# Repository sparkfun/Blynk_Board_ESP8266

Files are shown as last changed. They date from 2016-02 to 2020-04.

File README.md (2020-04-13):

SparkFun Blynk Board - ESP8266
========================================

SparkFun Blynk Board - ESP8266 (https://www.sparkfun.com/products/13794)

[*SparkFun Blynk Board - ESP8266 (WRL-13794)*](https://www.sparkfun.com/products/13794)

The SparkFun Blynk Board is specially designed to work with the [Blynk mobile app](http://blynk.cc), for iOS or Android devices. Combining the Blynk Board with the Blynk app, you'll be able to easily complete a variety of Internet-of-Things (IoT) based projects: control LEDs from your phone! Wire up a door switch and receive phone notifications when it opens or closes. Plug a soil moisture sensor into a plant, and have it tweet at you when it's thirsty!

BotaniTweet Project (https://learn.sparkfun.com/tutorials/blynk-board-project-guide/)

All of these projects - and more! - are pre-loaded into the Blynk Board. All you have to do is provision it (using the Blynk app), and start tinkering!

Repository Contents
-------------------

* **/Firmware** - Blynk Board core firmware and example code.
* **/Hardware** - Eagle design files (.brd, .sch)
* **/Production** - Production panel files (.brd)

Documentation
--------------
* **[Getting Started Guide](https://learn.sparkfun.com/tutorials/getting-started-with-the-sparkfun-blynk-board)** - Learn how to connect your Blynk Board to Wi-Fi, and start Blynking!
* **[Blynk Board Project Guide](https://learn.sparkfun.com/tutorials/blynk-board-project-guide/introduction)** - Explore over a dozen Blynk projects pre-loaded into the Blynk Board.
* **[Blynk Board Arduino Development Guide](https://learn.sparkfun.com/tutorials/blynk-board-arduino-development-guide)** - Learn how to begin programming the Blynk Board using Arduino, so you can create projects of your own!
* **[SparkFun Graphical Datasheets](https://github.com/sparkfun/Graphical_Datasheets/tree/master/Datasheets/ESP8266/BlynkBoard)** -Graphical Datasheets for the SparkFun Blynk Board.

Product Versions
----------------
* [SparkFun Blynk Board - ESP8266 (v1.0) (WRL-13794)](https://www.sparkfun.com/products/13794)- Initial release of the SparkFun Blynk Board - ESP8266.
* IoT Starter Kit with Blynk Board
  * [(KIT-14682)](https://www.sparkfun.com/products/14682) - Updated parts kit with thicker resistor leads.
  * [(KIT-13865)](https://www.sparkfun.com/products/13865) - A parts kit including the SparkFun Blynk Board.

Version History
---------------
* [HW v1.0, FW v1.0.3](https://github.com/sparkfun/Blynk_Board_ESP8266/releases/tag/HW_v1.0-FW_v1.0.3) - Minor update for ESP8266 Community board add on (v2.6.0 and above) when using interrupts.
* [HW v1.0, FW v1.0.2](https://github.com/sparkfun/Blynk_Board_ESP8266/releases/tag/HW_v1.0-FW_v1.0.2) - Initial release of the SparkFun Blynk Board hardware and firmware.

License Information
-------------------

This product is _**open source**_! 

Please review the LICENSE.md file for license information. 

If you have any questions or concerns on licensing, please contact technical support on our [SparkFun forums](https://forum.sparkfun.com/viewforum.php?f=152).

Distributed as-is; no warranty is given.

- Your friends at SparkFun.

_<COLLABORATION CREDIT>_

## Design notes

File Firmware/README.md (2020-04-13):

# SparkFun Blynk Board - ESP8266 Core Firmware

The [SparkFun Blynk Board - ESP8266](https://www.sparkfun.com/products/13794) firmware allows you to configure a Blynk Board's WiFi network and Blynk auth token. Then, once the board is equipped with network access and a connection to the Blynk Cloud, the firmware is equipped with ten Blynk experiments, which allows you to test out the Blynk Board and the Blynk app without ever bothering to re-program the board's ESP8266 WiFi/microcontroller.

### Firmware Contents

To better navigate the firmware's functionality, the source code is divided into a number of separate files:

* **[BlynkBoard_Core_Firmware.ino](https://github.com/sparkfun/Blynk_Board_ESP8266/Firmware/BlynkBoard_Core_Firmware.ino)** -- Main source file, where `setup()` and `loop()` are defined. Also controls the RGB LED status indicator.
* **[BlynkBoard_Setup.ino](https://github.com/sparkfun/Blynk_Board_ESP8266/Firmware/BlynkBoard_Setup.ino)** -- Hardware setup and EEPROM/flash reading/writing.
* **[BlynkBoard_ConfigMode.ino](https://github.com/sparkfun/Blynk_Board_ESP8266/Firmware/BlynkBoard_ConfigMode.ino)** -- Configuration mode functions; AP and serial WiFi/Blynk configuration.
* **[BlynkBoard_BlynkMode.ino](https://github.com/sparkfun/Blynk_Board_ESP8266/Firmware/BlynkBoard_BlynkMode.ino)** -- Blynk mode functions, including definition of all Blynk Board introductory experiments.
* **[BlynkBoard_settings.h](https://github.com/sparkfun/Blynk_Board_ESP8266/Firmware/BlynkBoard_settings.h)** -- Various constant settings, including RGB colors and connection timeouts.

### Using Arduino to Upload to the Blynk Board

For help adding Blynk Board support to your Arduino IDE, check out our [Blynk Board Arduino Development Guide](https://learn.sparkfun.com/tutorials/blynk-board-arduino-development-guide).

You can install the board definitions using the **Arduino Board Manager**. Just paste the link below into the "Additional Board URL's" textbox, in Arduino properties:

	http://arduino.esp8266.com/stable/package_esp8266com_index.json

After installing the Arduino ESP8266 board definitions, you'll find a option for "SparkFun Blynk Board" under the **Tools** > **Board** menu - select that, and upload some code!

### Custom Libraries Used

If you are installing the Bynk Board Core Firmware, you will need to install a few Arduino libraries. For more infomration, check out the tutorial for intsalling an Arduino Library.

* **[Installing an Arduino Library Guide](https://learn.sparkfun.com/tutorials/installing-an-arduino-library)** - Basic information on how to install an Arduino library.

The following libraries were used with the default Blynk Board Core Firmware:

* [Blynk Arduino Library](https://github.com/blynkkk/blynk-library/releases/tag/v0.3.4)
* [SparkFun HTU21D](https://github.com/sparkfun/SparkFun_HTU21D_Breakout_Arduino_Library/releases/tag/V_1.1.1)
* [Adafruit NeoPixel](https://github.com/adafruit/Adafruit_NeoPixel)
* [SparkFun TSL2561 Library](https://github.com/sparkfun/SparkFun_TSL2561_Arduino_Library/releases/tag/V_1.1.0)

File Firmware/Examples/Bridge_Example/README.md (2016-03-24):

These two example sketches are nearly identical. The key difference is the
authentication tokens will be swapped in the two. This example code for the
SparkFun Blynk Board demonstrates the functionality of the Bridge widget.
Using two of these boards to send signals from one board to the other, or from
one connected mobile device to either Blynk Board or another mobile device if
available. Simple wireless buttons and a more complex chat app are part of this
demo.

For more information please see the [tutorial](https://learn.sparkfun.com/tutorials/blynk-board-bridge-widget-demo/) on the SparkFun website.

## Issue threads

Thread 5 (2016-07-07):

Firmware + Interrupts

mrmolex, 2016-07-07:
Hi!.  The digital pins can handle interrupts? in which pins? what limitations have?.  NOTE: i need to count a pulse signal with a max. frequency of 2 Hz.

bboyho, 2020-04-13:
Hi,

This case looks stale and does not seem to be an issue with the Blynk board or core firmware. However, I can answer a few of your questions:

If you are still wondering, [all the ESP8266's digital pins can handle interrupts except for GPIO16](https://arduino-esp8266.readthedocs.io/en/2.6.3/reference.html#digital-io). When using the ESP8266 community's board definition (v2.5.1 and above) for the ESP8266, you must include `ICACHE_RAM_ATTR` before the function definition. For additional limitations, check out the [reference guide for the ESP8266](https://arduino-esp8266.readthedocs.io/en/2.6.3/reference.html#interrupts) . In terms of the ESP8266 and the Blynk app, the minimum update rate is 1 second. I have not tried this before but you could [manually set the rate](https://docs.blynk.cc/#blynk-main-operations-get-data-from-hardware-pushing-data-from-hardware) for anything less than a second using the PUSH option.

Closed 2020-04-13.

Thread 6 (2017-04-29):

Arduino Error - error: 'class Adafruit_NeoPixel' has no member named 'updateLength'    rgb.updateLength(ledCount);

YMLkris, 2017-04-29:
Hello all,

When compiling the firmware in the Arduino IDE, I am getting error messages in both files which use rgb.updateLength. I have installed / updated all of the libraries listed, including Adafruit NeoPixel.  The error is:

Arduino: 1.6.11 (Mac OS X), Board: "SparkFun Blynk Board, 80 MHz, Serial, 115200, 4M (1M SPIFFS)"

/Users/kriss/Documents/Arduino/Blynk_Board_ESP8266/Firmware/BlynkBoard_Core_Firmware/BlynkBoard_BlynkMode.ino: In function 'void BlynkWidgetWrite29(BlynkReq&, const BlynkParam&)':
BlynkBoard_BlynkMode:373: error: 'class Adafruit_NeoPixel' has no member named 'updateLength'
   rgb.updateLength(ledCount);
       ^
/Users/kriss/Documents/Arduino/Blynk_Board_ESP8266/Firmware/BlynkBoard_Core_Firmware/BlynkBoard_Setup.ino: In function 'void performSelfTest()':
BlynkBoard_Setup:337: error: 'class Adafruit_NeoPixel' has no member named 'updateLength'
   rgb.updateLength(2); // Connect to testbed LED
       ^
Multiple libraries were found for "Servo.h"
 Used: /Users/kriss/Library/Arduino15/packages/esp8266/hardware/esp8266/2.1.0/libraries/Servo
 Not used: /Applications/Arduino.app/Contents/Java/libraries/Servo
Multiple libraries were found for "Adafruit_NeoPixel.h"
 Used: /Users/kriss/Documents/Arduino/libraries/Adafruit_NeoPixel
 Not used: /Users/kriss/Library/Arduino15/packages/esp8266/hardware/esp8266/2.1.0/libraries/Adafruit_NeoPixel
Multiple libraries were found for "BlynkSimpleEsp8266.h"
 Used: /Users/kriss/Documents/Arduino/libraries/Blynk
 Not used: /Users/kriss/Library/Arduino15/packages/esp8266/hardware/esp8266/2.1.0/libraries/Blynk
 Not used: /Users/kriss/Library/Arduino15/packages/esp8266/hardware/esp8266/2.1.0/libraries/Blynk
 Not used: /Users/kriss/Library/Arduino15/packages/esp8266/hardware/esp8266/2.1.0/libraries/Blynk
 Not used: /Users/kriss/Library/Arduino15/packages/esp8266/hardware/esp8266/2.1.0/libraries/Blynk
Multiple libraries were found for "SparkFunHTU21D.h"
 Used: /Users/kriss/Documents/Arduino/libraries/SparkFun_HTU21D_Humidity_and_Temperature_Sensor_Breakout
 Not used: /Users/kriss/Library/Arduino15/packages/esp8266/hardware/esp8266/2.1.0/libraries/SparkFun_HTU21D_Humidity_and_Temperature_Sensor_Breakout
 Not used: /Users/kriss/Library/Arduino15/packages/esp8266/hardware/esp8266/2.1.0/libraries/SparkFun_HTU21D_Humidity_and_Temperature_Sensor_Breakout
 Not used: /Users/kriss/Library/Arduino15/packages/esp8266/hardware/esp8266/2.1.0/libraries/SparkFun_HTU21D_Humidity_and_Temperature_Sensor_Breakout
 Not used: /Users/kriss/Library/Arduino15/packages/esp8266/hardware/esp8266/2.1.0/libraries/SparkFun_HTU21D_Humidity_and_Temperature_Sensor_Breakout
Multiple libraries were found for "SparkFunTSL2561.h"
 Used: /Users/kriss/Documents/Arduino/libraries/SparkFun_TSL2561
 Not used: /Users/kriss/Library/Arduino15/packages/esp8266/hardware/esp8266/2.1.0/libraries/SparkFun_TSL2561
 Not used: /Users/kriss/Library/Arduino15/packages/esp8266/hardware/esp8266/2.1.0/libraries/SparkFun_TSL2561
 Not used: /Users/kriss/Library/Arduino15/packages/esp8266/hardware/esp8266/2.1.0/libraries/SparkFun_TSL2561
 Not used: /Users/kriss/Library/Arduino15/packages/esp8266/hardware/esp8266/2.1.0/libraries/SparkFun_TSL2561
exit status 1
'class Adafruit_NeoPixel' has no member named 'updateLength'

This report would have more information with
"Show verbose output during compilation"
option enabled in File -> Preferences.

bboyho, 2019-02-11:
Hi,

There are two things that might be causing the compile error. If you do not have the library installed to the correct path, the Arduino IDE will have issues compiling since it is not able to understand the functions defined. This is a common issue.  For more information, check out the tutorial on installing the library using the [Arduino Library Manager](https://learn.sparkfun.com/tutorials/installing-an-arduino-library/all#using-the-arduino-library-manager). Simply search for "**NeoPixel**" to automatically install the [NeoPixel library](https://github.com/adafruit/Adafruit_NeoPixel).

Also, make sure that you have the following files in the [same folder as the **BlynkBoard_Core_Firmware.ino**](https://github.com/sparkfun/Blynk_Board_ESP8266/tree/master/Firmware/BlynkBoard_Core_Firmware) or you will have issues compiling:

* BlynkBoard_BlynkMode.ino
* BlynkBoard_ConfigMode.ino
* BlynkBoard_Setup.ino
* BlynkBoard_settings.h

The **BlynkBoard_settings.h** file is where `rgb` is defined so that we can use the library => [https://github.com/sparkfun/Blynk_Board_ESP8266/blob/master/Firmware/BlynkBoard_Core_Firmware/BlynkBoard_settings.h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]9https://github.com/sparkfun/Blynk_Board_ESP8266/blob/master/Firmware/BlynkBoard_Core_Firmware/BlynkBoard_settings.h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) .

Closed 2019-02-11.

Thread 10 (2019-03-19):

How to update ESP8266 library for Sparkfun add-on

hanaldo, 2019-03-19:
Not sure where I can ask this issue but I was recommended to post it here. In order to program the Sparkfun Blynk Board I installed the [add-on](https://raw.githubusercontent.com/sparkfun/Arduino_Boards/master/IDE_Board_Manager/package_sparkfun_index.json), but this add-on is using Blynk library v0.3.1 and ESP8266 library v2.1.0, I really do wish to update the ESP8266 library to its newest version due to some bugs and incompatibility issue to newest Blynk library. But I couldn't do so with the add-on, does anyone know how to update the ESP8266 core for Sparkfun add-on or is there any other way we can program the Sparkfun Blynk Board without its add-on?

hanaldo, 2019-11-01:
It looks like the Sparkfun Blynk board [add-on](https://raw.githubusercontent.com/sparkfun/Arduino_Boards/master/IDE_Board_Manager/package_sparkfun_index.json) was updated, it is now using ESP8266 core v2.1.2 instead of v2.1.0, but it is actually broken. After I install the add-on it misses a lot of necessary non-ESP8266 libraries, such as Blynk library, SparkFun_HTU21D, SparkFun_TSL2561, then I have to install them all manually. Finally, the ESP8266 core v2.1.2 core can only compile with Blynk v0.5.2 and below, I was forced to dig into this myself. Btw, the [document](https://cdn.sparkfun.com/assets/learn_tutorials/4/9/5/Blynk-_Community_ESP8266_Boards.pdf) from Sparkfun for troubleshooting ESP8266 community board does not work at all!

hanaldo, 2019-11-01:
I wanted to use the most up-to-date Blynk library, which is now v0.6.1. So, I manually updated my Blynk library to v0.6.1, and it is not compatible with ESP8266 core v2.1.2, then I manually updated my ESP8266 core to v2.5.2, and updated its "boards.txt" file to include my Sparkfun Blynk Board configuration. It can compile and run, but the board will throw an error of "ISR not in IRAM!" when running the Sparkfun's firmware. According to this [post](https://community.blynk.cc/t/error-isr-not-in-iram/37426/10), I downgraded my ESP8266 core to v2.4.2, and now everything works fine. In short, now I can flash my Sparkfun Blynk Board with Blynk library v0.6.1 and ESP8266 core v2.4.2!

hanaldo, 2019-11-01:
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

Closed 2019-11-01.

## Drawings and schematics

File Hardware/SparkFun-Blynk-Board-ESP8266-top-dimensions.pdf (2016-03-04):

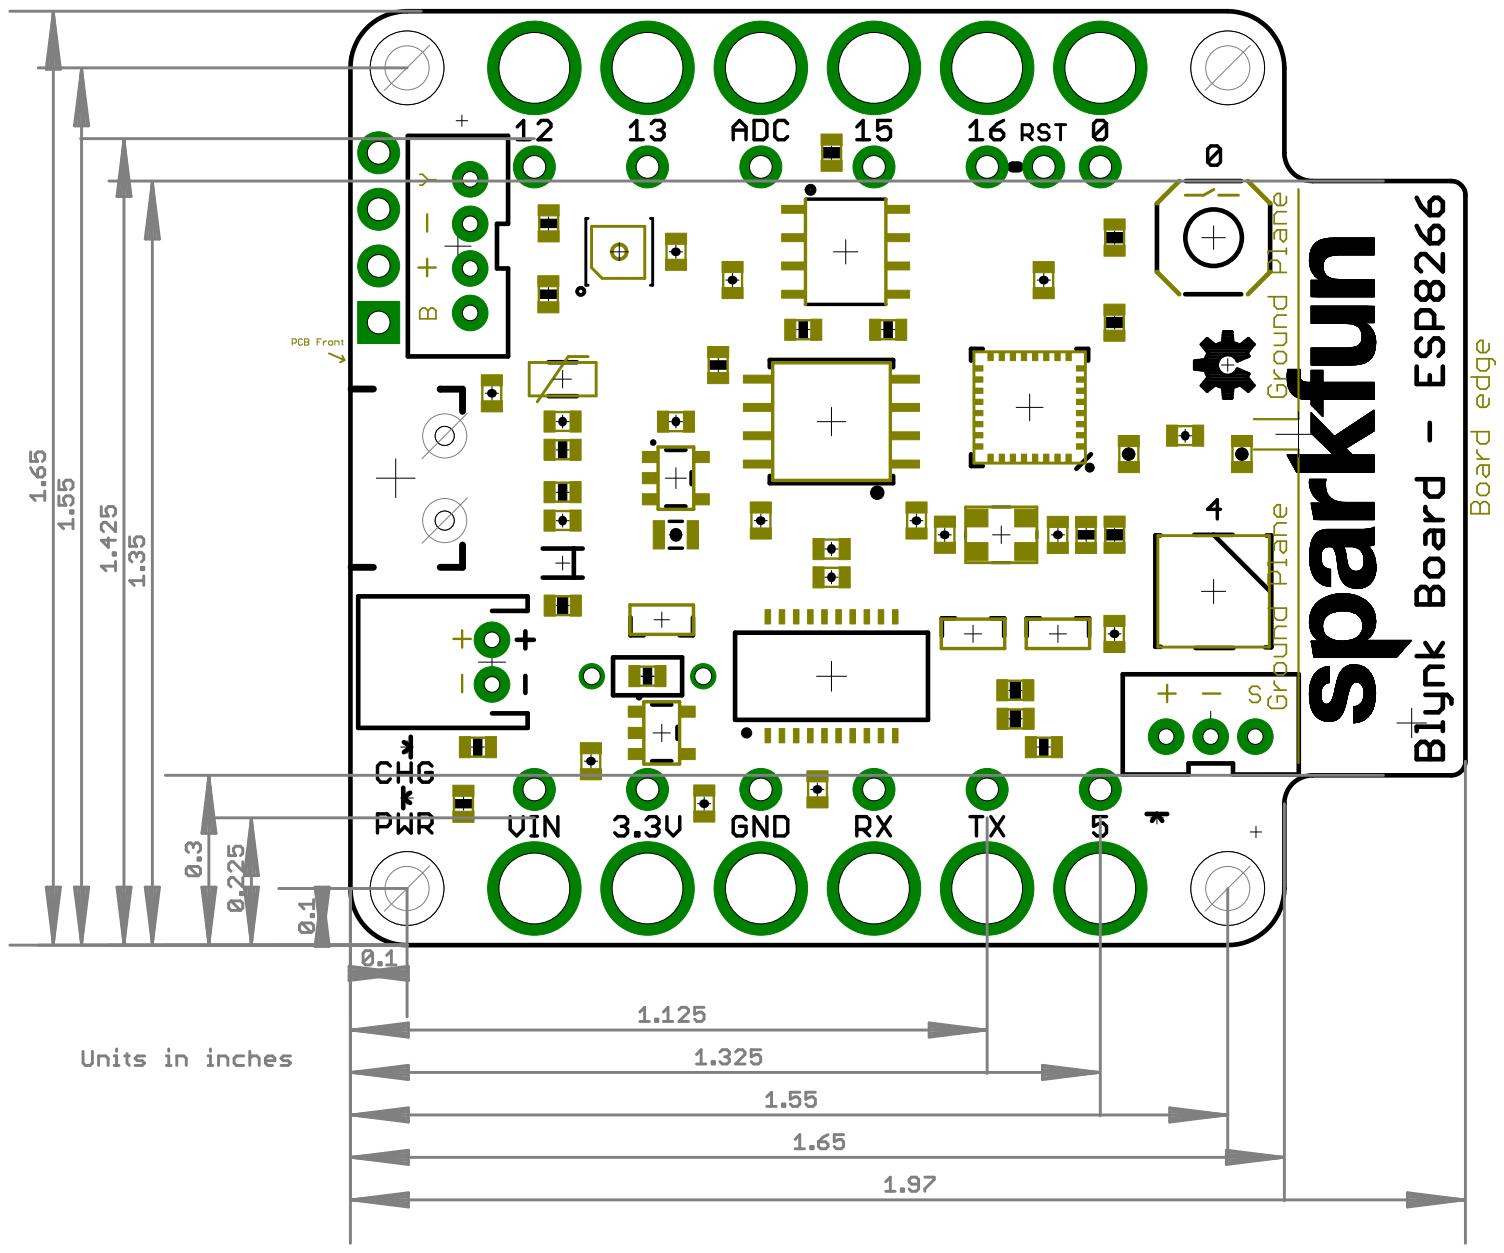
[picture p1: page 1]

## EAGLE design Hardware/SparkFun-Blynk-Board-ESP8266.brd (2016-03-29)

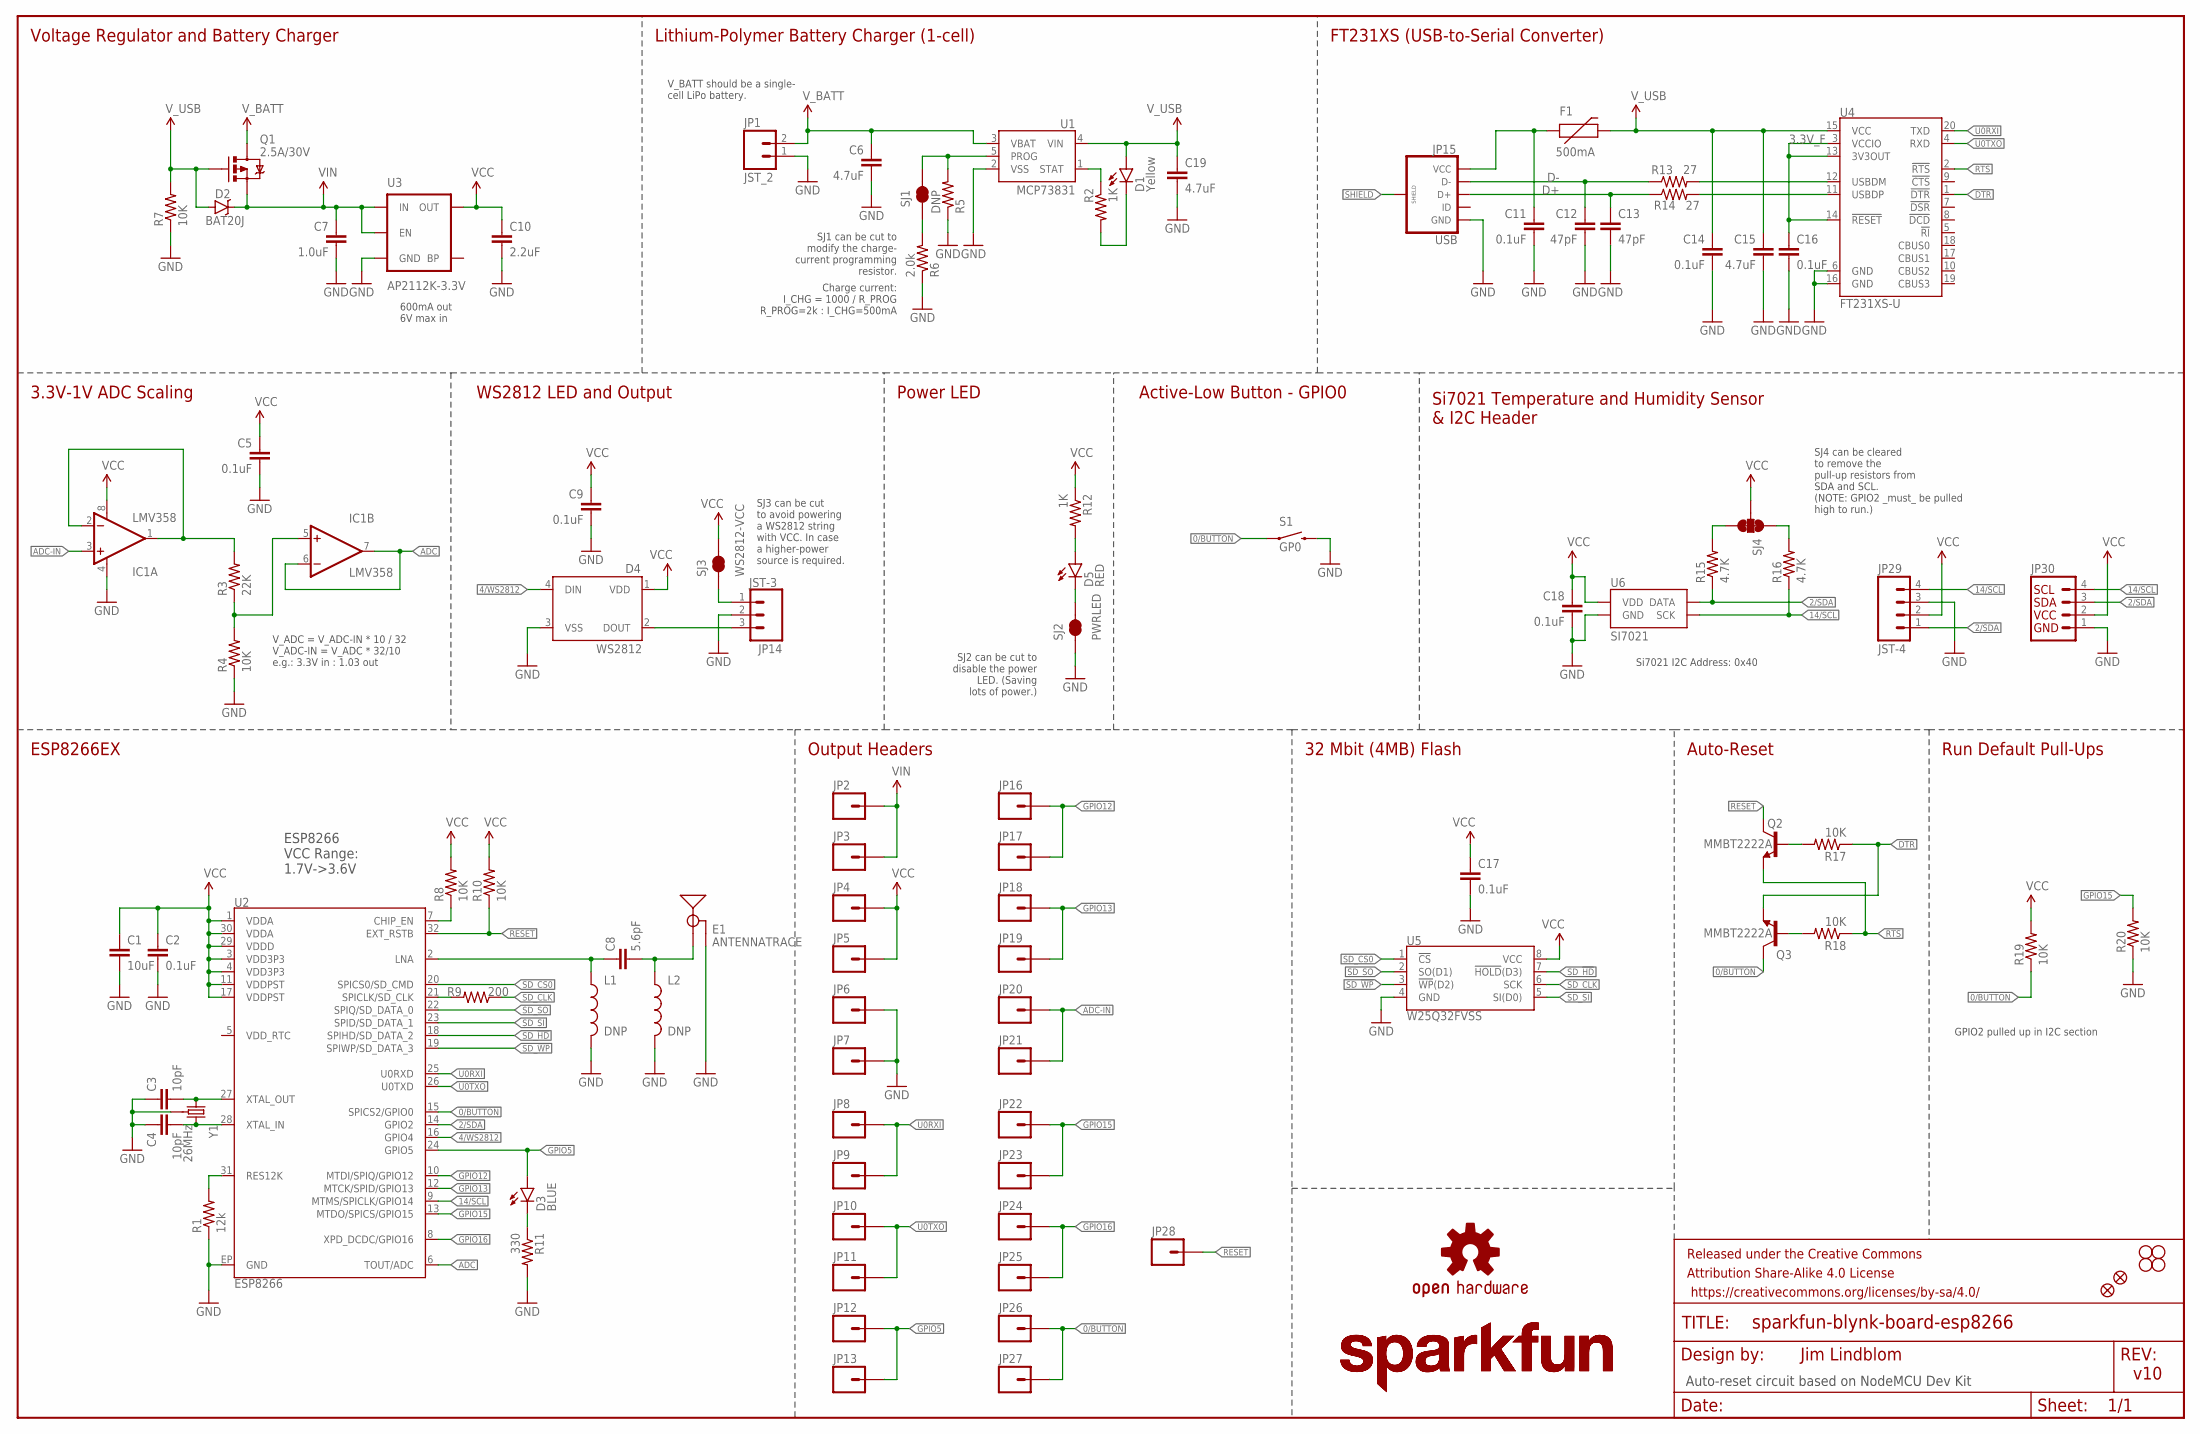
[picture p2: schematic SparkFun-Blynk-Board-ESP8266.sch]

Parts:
C1: 10uF; 0603-CAP
C2, C5, C9, C11, C14, C16, C17, C18: 0.1uF; 0603-CAP
C3, C4: 10pF; 0603-CAP
C6, C15, C19: 4.7uF; 0603-CAP
C7: 1.0uF; 0805-CAP
C8: 5.6pF; 0603-CAP
C10: 2.2uF; 0603-CAP
C12, C13: 47pF; 0603-CAP
D1: Yellow; LED-0603
D2: BAT20J; SOD-323
D3: BLUE; LED-0603
D4: WS2812; WS2812B
D5: RED; LED-0603
E1: ANTENNATRACE; TRACE_ANTENNA_2.4GHZ_25.7MM
F1: 500mA; PTC-1206
FID1, FID2: FIDUCIAL1X2; FIDUCIAL-1X2
FRAME1: FRAME-LEDGER; CREATIVE_COMMONS
IC1: LMV358; SO08
JP1: JST_2; JST-2-PTH
JP2, JP4, JP6, JP8, JP10, JP12, JP16, JP18, JP20, JP22, JP24, JP26: DNP; 1X01_ALLIGATOR_3MM_HALF
JP3, JP5, JP7, JP9, JP11, JP13, JP17, JP19, JP21, JP23, JP25, JP27, JP28: DNP; 1X01_NO_SILK
JP14: JST-3; JST-3-PTH-VERT
JP15: USB; USB-B-MICRO-SMD_V03
JP29: JST-4; JST-4-PTH-VERT
JP30: DNP; 1X04_NO_SILK
L1, L2: DNP; 0603
LOGO1: SFE_LOGO_NAME.2_INCH; SFE_LOGO_NAME_.2
LOGO2: OSHW-LOGOS; OSHW-LOGO-S
LOGO3: SFE_LOGO_NAME.3_INCH; SFE_LOGO_NAME_.3
Q1: 2.5A/30V; SOT23-3
Q2, Q3: MMBT2222A; SOT23-3@1
R1: 12k; 0603-RES
R2, R12: 1K; 0603-RES
R3: 22K; 0603-RES
R4: 10K; 0603-RES
R5: DNP; 1/6W-RES
R6: 2.0k; 0603-RES
R7, R8, R10, R17, R18, R19, R20: 10K; 0603-RES@1
R9: 200; 0603-RES
R11: 330; 0603-RES
R13, R14: 27; 0603-RES
R15, R16: 4.7K; 0603-RES
S1: GP0; TACTILE-SWITCH-SMD
SJ1: DNP; PAD-JUMPER-2-NC_BY_TRACE_YES_SILK
SJ2: PWRLED; PAD-JUMPER-2-NC_BY_TRACE_YES_SILK
SJ3: WS2812-VCC; PAD-JUMPER-2-NC_BY_TRACE_YES_SILK
SJ4: DNP; PAD-JUMPER-3-3OF3_NC_BY_TRACE_YES_SILK_FULL_BOX
STANDOFF1, STANDOFF2, STANDOFF3, STANDOFF4: STAND-OFF
U1: MCP73831; SOT23-5
U2: ESP8266; QFN32
U3: AP2112K-3.3V; SOT23-5
U4: FT231XS-U; SSOP20_L
U5: W25Q32FVSS; SOIC-8
U6: SI7021
Y1: 26MHz; CRYSTAL-SMD-3.2X2.5

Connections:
0/BUTTON: JP26.1@2, JP27.1, Q3.3 (C), R19.1, S1.1, S1.2 (1), U2.15 (SPICS2/GPIO0)
2/SDA: JP29.1, JP30.3, R15.1, U2.14 (GPIO2), U6.DATA
3.3V_F: C16.1, U4.3 (VCCIO), U4.13 (3V3OUT), U4.14 (!RESET)
4/WS2812: D4.4 (DIN), U2.16 (GPIO4)
14/SCL: JP29.4, JP30.4, R16.1, U2.9 (MTMS/SPICLK/GPIO14), U6.SCK
ADC: IC1.6 (-IN), IC1.7 (OUT), U2.6 (TOUT/ADC)
ADC-IN: IC1.3 (+IN), JP20.1@2, JP21.1
CHIP_EN: R8.1, U2.7 (CHIP_EN)
D+: C13.1, JP15.D+, R14.1
D-: C12.1, JP15.D-, R13.1
DTR: Q3.2 (E), R17.1, U4.1 (!DTR)
GND: C1.2, C2.2, C3.1, C4.1, C5.2, C6.2, C7.2, C9.2, C10.2, C11.2, C12.2, C13.2, C14.2, C15.2, C16.2, C17.2, C18.2, C19.2, D4.3 (VSS), E1.GND, E1.GND2 (GND), IC1.4 (V-), JP1.1, JP6.1@2, JP7.1, JP14.2, JP15.GND, JP29.3, JP30.1, L1.2, L2.2, R1.1, R4.1, R5.1, R6.1, R7.1, R11.2, R20.1, S1.3 (2), S1.4 (2), SJ2.1, U1.2 (VSS), U2.EP (GND), U3.2 (GND), U4.6 (GND), U4.16 (GND), U5.4 (GND), U6.GND, Y1.2 (GND), Y1.4 (GND)
GPIO5: D3.A, JP12.1@2, JP13.1, U2.24 (GPIO5)
GPIO12: JP16.1@2, JP17.1, U2.10 (MTDI/SPIQ/GPIO12)
GPIO13: JP18.1@2, JP19.1, U2.12 (MTCK/SPID/GPIO13)
GPIO15: JP22.1@2, JP23.1, R20.2, U2.13 (MTDO/SPICS/GPIO15)
GPIO16: JP24.1@2, JP25.1, U2.8 (XPD_DCDC/GPIO16)
LNA: C8.1, L1.1, U2.2 (LNA)
unnamed: R1.2, U2.31 (RES12K)
unnamed: C4.2, U2.28 (XTAL_IN), Y1.3 (2)
unnamed: C3.2, U2.27 (XTAL_OUT), Y1.1
unnamed: R13.2, U4.12 (USBDM)
unnamed: D5.C, SJ2.2
unnamed: Q2.1 (B), R17.2
unnamed: R14.2, U4.11 (USBDP)
unnamed: D3.C, R11.1
unnamed: R2.1, U1.1 (STAT)
unnamed: D5.A, R12.2
unnamed: R15.2, SJ4.3
unnamed: Q3.1 (B), R18.2
unnamed: R16.2, SJ4.1
unnamed: R5.2, SJ1.2, U1.5 (PROG)
unnamed: IC1.1 (OUT), IC1.2 (-IN), R3.2
unnamed: R6.2, SJ1.1
unnamed: D1.C, R2.2
unnamed: IC1.5 (+IN), R3.1, R4.2
unnamed: JP14.1, SJ3.1
RESET: JP28.1, Q2.3 (C), R10.1, U2.32 (EXT_RSTB)
RTS: Q2.2 (E), R18.1, U4.2 (!RTS)
SD_!HD!: U2.18 (SPIHD/SD_DATA_2), U5.7 (!HOLD!(D3))
SD_!WP!: U2.19 (SPIWP/SD_DATA_3), U5.3 (!WP!(D2))
SD_CLK: R9.1, U5.6 (SCK)
SD_CLK0: R9.2, U2.21 (SPICLK/SD_CLK)
SD_CS0: U2.20 (SPICS0/SD_CMD), U5.1 (!CS!)
SD_SI: U2.23 (SPID/SD_DATA_1), U5.5 (SI(D0))
SD_SO: U2.22 (SPIQ/SD_DATA_0), U5.2 (SO(D1))
SHIELD: JP15.SHIELD1 (SHIELD), JP15.SHIELD2 (SHIELD), JP15.SHIELD3 (SHIELD)
TRACE_ANT: C8.2, E1.ANT (SIGNAL), L2.1
U0RXI: JP8.1@2, JP9.1, U2.25 (U0RXD), U4.20 (TXD)
U0TXO: JP10.1@2, JP11.1, U2.26 (U0TXD), U4.4 (RXD)
VCC: C1.1, C2.1, C5.1, C9.1, C10.1, C17.1, C18.1, D4.1 (VDD), IC1.8 (V+), JP4.1@2, JP5.1, JP29.2, JP30.2, R8.2, R10.2, R12.1, R19.2, SJ3.2, SJ4.2, U2.1 (VDDA), U2.3 (VDD3P3), U2.4 (VDD3P3), U2.11 (VDDPST), U2.17 (VDDPST), U2.29 (VDDD), U2.30 (VDDA), U3.5 (OUT), U5.8 (VCC), U6.VDD
VIN: C7.1, D2.C, JP2.1@2, JP3.1, Q1.2 (S), U3.1 (IN), U3.3 (EN)
VUSB: C11.1, F1.1, JP15.VBUS (VCC)
V_BATT: C6.1, JP1.2, Q1.3 (D), U1.3 (VBAT)
V_USB: C14.1, C15.1, C19.1, D1.A, D2.A, F1.2, Q1.1 (G), R7.2, U1.4 (VIN), U4.15 (VCC)
WS2812-DOUT: D4.2 (DOUT), JP14.3

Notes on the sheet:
ESP8266EX
ESP8266 VCC Range: 1.7V->3.6V
FT231XS (USB-to-Serial Converter)
Auto-Reset
Run Default Pull-Ups
SJ2 can be cut to disable the power LED. (Saving lots of power.)
Jim Lindblom
v10
Auto-reset circuit based on NodeMCU Dev Kit
GPIO2 pulled up in I2C section
V_BATT should be a single- cell LiPo battery.
Charge current: I_CHG = 1000 / R_PROG R_PROG=2k : I_CHG=500mA
32 Mbit (4MB) Flash
Output Headers
3.3V-1V ADC Scaling
WS2812 LED and Output
Active-Low Button - GPIO0
Si7021 Temperature and Humidity Sensor & I2C Header
Voltage Regulator and Battery Charger
SJ1 can be cut to modify the charge- current programming resistor.
SJ4 can be cleared to remove the pull-up resistors from SDA and SCL. (NOTE: GPIO2 _must_ be pulled high to run.)
Si7021 I2C Address: 0x40
Lithium-Polymer Battery Charger (1-cell)
Power LED
SJ3 can be cut to avoid powering a WS2812 string with VCC. In case a higher-power source is required.
V_ADC = V_ADC-IN * 10 / 32 V_ADC-IN = V_ADC * 32/10 e.g.: 3.3V in : 1.03 out
600mA out 6V max in

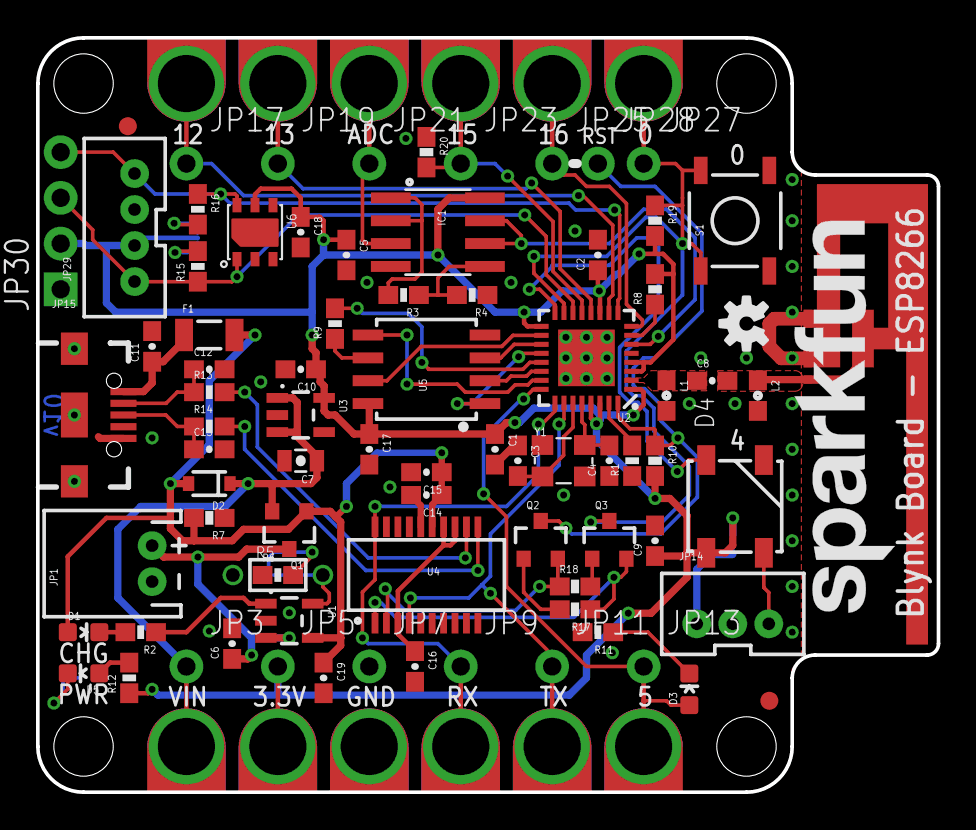
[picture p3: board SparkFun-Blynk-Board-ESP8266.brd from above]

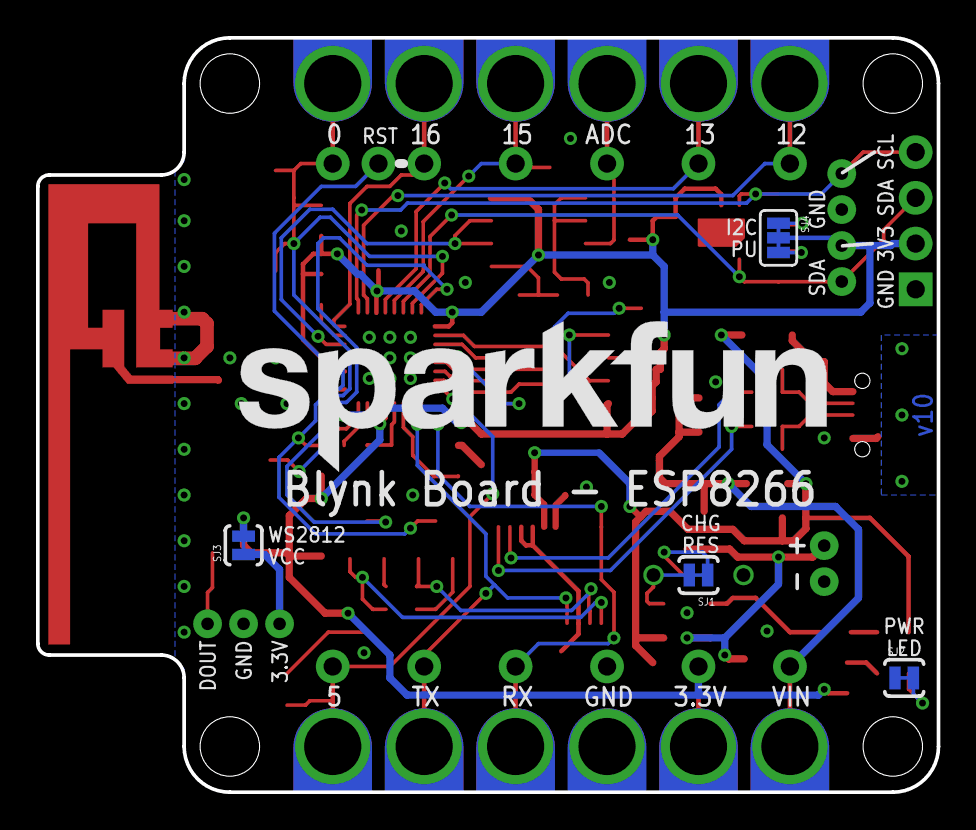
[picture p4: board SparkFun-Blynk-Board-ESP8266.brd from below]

Board: 2 copper layers, 50.0 x 41.9 mm, 104 parts (5 on the bottom side), 56 nets.

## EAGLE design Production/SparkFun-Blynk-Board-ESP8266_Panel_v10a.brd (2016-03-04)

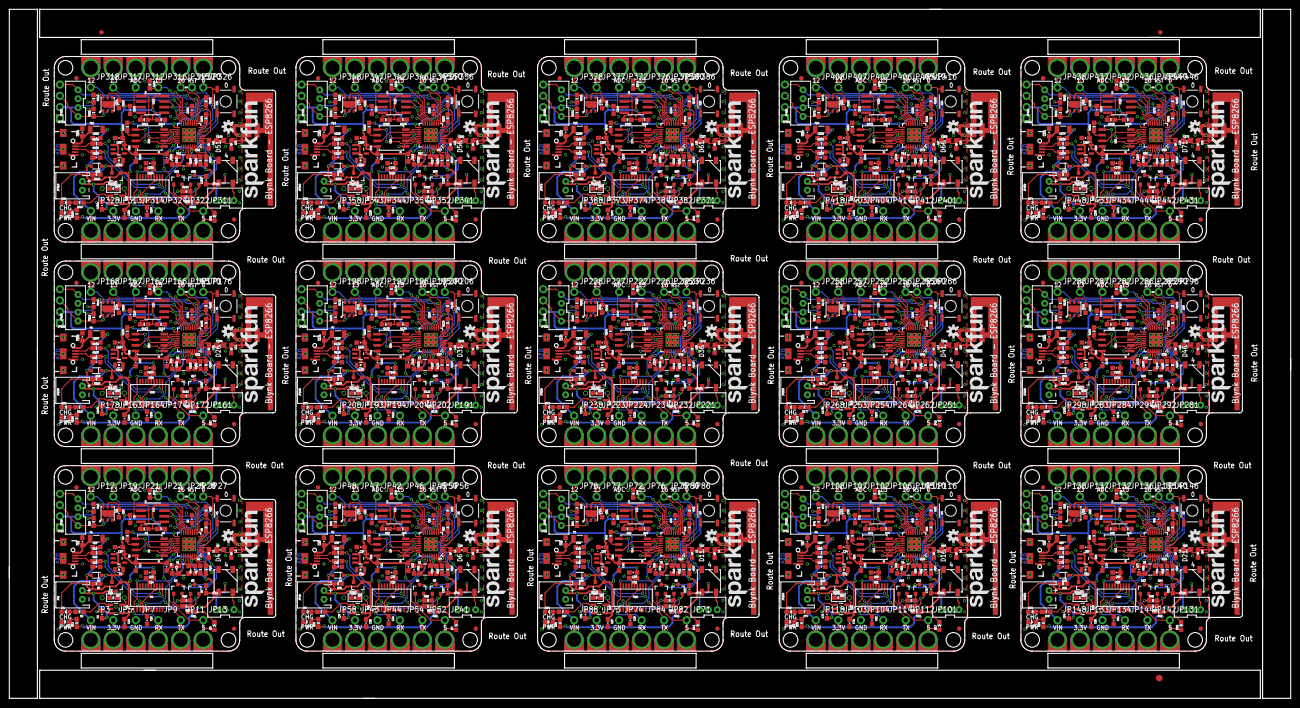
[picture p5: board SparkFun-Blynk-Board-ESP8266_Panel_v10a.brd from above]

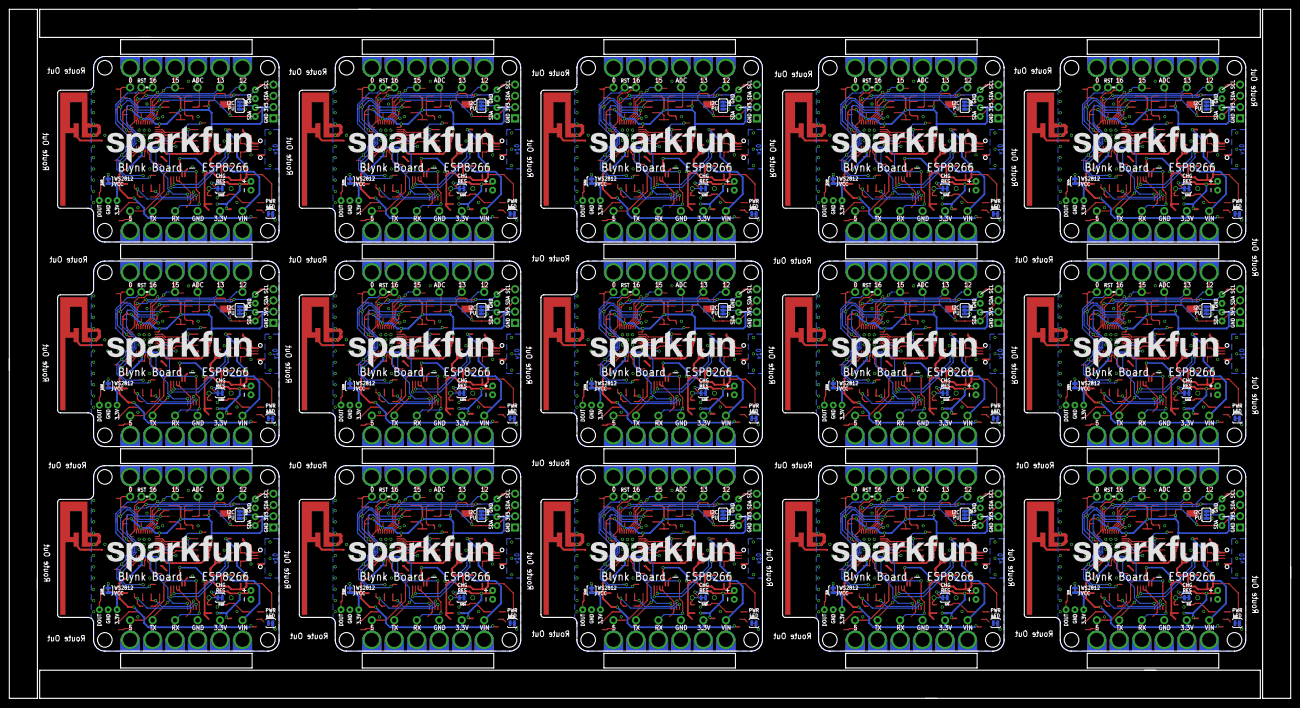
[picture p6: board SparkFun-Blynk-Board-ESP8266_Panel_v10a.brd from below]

Board: 2 copper layers, 289.6 x 155.7 mm, 1548 parts (75 on the bottom side), 840 nets.

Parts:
C1, C20, C39, C58, C77, C96, C115, C134, C153, C172, C191, C210, C229, C248, C267: 10uF; 0603-CAP
C2, C5, C9, C11, C14, C16, C17, C18, C21, C23, C24, C25, C29, C32, C33, C34, C40, C42, C43, C44, C48, C51, C52, C53, C59, C61, C62, C63, C67, C70, C71, C72, C78, C80, C81, C82, C86, C89, C90, C91, C97, C99, C100, C101, C105, C108, C109, C110, C116, C118, C119, C120, C124, C127, C128, C129, C135, C137, C138, C139, C143, C146, C147, C148, C154, C156, C157, C158, C162, C165, C166, C167, C173, C175, C176, C177, C181, C184, C185, C186, C192, C194, C195, C196, C200, C203, C204, C205, C211, C213, C214, C215, C219, C222, C223, C224, C230, C232, C233, C234, C238, C241, C242, C243, C249, C251, C252, C253, C257, C260, C261, C262, C268, C270, C271, C272, C276, C279, C280, C281: 0.1uF; 0603-CAP
C3, C4, C26, C27, C45, C46, C64, C65, C83, C84, C102, C103, C121, C122, C140, C141, C159, C160, C178, C179, C197, C198, C216, C217, C235, C236, C254, C255, C273, C274: 10pF; 0603-CAP
C6, C15, C19, C31, C37, C38, C50, C56, C57, C69, C75, C76, C88, C94, C95, C107, C113, C114, C126, C132, C133, C145, C151, C152, C164, C170, C171, C183, C189, C190, C202, C208, C209, C221, C227, C228, C240, C246, C247, C259, C265, C266, C278, C284, C285: 4.7uF; 0603-CAP
C7, C35, C54, C73, C92, C111, C130, C149, C168, C187, C206, C225, C244, C263, C282: 1.0uF; 0805-CAP
C8, C28, C47, C66, C85, C104, C123, C142, C161, C180, C199, C218, C237, C256, C275: 5.6pF; 0603-CAP
C10, C36, C55, C74, C93, C112, C131, C150, C169, C188, C207, C226, C245, C264, C283: 2.2uF; 0603-CAP
C12, C13, C22, C30, C41, C49, C60, C68, C79, C87, C98, C106, C117, C125, C136, C144, C155, C163, C174, C182, C193, C201, C212, C220, C231, C239, C250, C258, C269, C277: 47pF; 0603-CAP
D1, D9, D14, D19, D24, D29, D34, D39, D44, D49, D54, D59, D64, D69, D74: Yellow; LED-0603
D2, D8, D13, D18, D23, D28, D33, D38, D43, D48, D53, D58, D63, D68, D73: BAT20J; SOD-323
D3, D7, D12, D17, D22, D27, D32, D37, D42, D47, D52, D57, D62, D67, D72: BLUE; LED-0603
D4, D6, D11, D16, D21, D26, D31, D36, D41, D46, D51, D56, D61, D66, D71: WS2812; WS2812B
D5, D10, D15, D20, D25, D30, D35, D40, D45, D50, D55, D60, D65, D70, D75: RED; LED-0603
E1, E2, E3, E4, E5, E6, E7, E8, E9, E10, E11, E12, E13, E14, E15: ANTENNATRACE; TRACE_ANTENNA_2.4GHZ_25.7MM
E$1: FIDUCIAL-1.5X3
E$7, E$8: FIDUCIAL-1X2
F1, F2, F3, F4, F5, F6, F7, F8, F9, F10, F11, F12, F13, F14, F15: 500mA; PTC-1206
FID1, FID2, FID3, FID4, FID5, FID6, FID7, FID8, FID9, FID10, FID11, FID12, FID13, FID14, FID15, FID16, FID17, FID18, FID19, FID20, FID21, FID22, FID23, FID24, FID25, FID26, FID27, FID28, FID29, FID30: FIDUCIAL1X2; FIDUCIAL-1X2
IC1, IC2, IC3, IC4, IC5, IC6, IC7, IC8, IC9, IC10, IC11, IC12, IC13, IC14, IC15: LMV358; SO08
JP1, JP49, JP79, JP109, JP139, JP169, JP199, JP229, JP259, JP289, JP319, JP349, JP379, JP409, JP439: LiPo; JST-2-PTH
JP2, JP4, JP6, JP8, JP10, JP12, JP16, JP18, JP20, JP22, JP24, JP26, JP32, JP33, JP34, JP35, JP36, JP37, JP38, JP39, JP51, JP53, JP55, JP57, JP62, JP63, JP64, JP65, JP66, JP67, JP68, JP69, JP81, JP83, JP85, JP87, JP92, JP93, JP94, JP95, JP96, JP97, JP98, JP99, JP111, JP113, JP115, JP117, JP122, JP123, JP124, JP125, JP126, JP127, JP128, JP129, JP141, JP143, JP145, JP147, JP152, JP153, JP154, JP155, JP156, JP157, JP158, JP159, JP171, JP173, JP175, JP177, JP182, JP183, JP184, JP185, JP186, JP187, JP188, JP189, JP201, JP203, JP205, JP207, JP212, JP213, JP214, JP215, JP216, JP217, JP218, JP219, JP231, JP233, JP235, JP237, JP242, JP243, JP244, JP245, JP246, JP247, JP248, JP249, JP261, JP263, JP265, JP267, JP272, JP273, JP274, JP275, JP276, JP277, JP278, JP279, JP291, JP293, JP295, JP297, JP302, JP303, JP304, JP305, JP306, JP307, JP308, JP309, JP321, JP323, JP325, JP327, JP332, JP333, JP334, JP335, JP336, JP337, JP338, JP339, JP351, JP353, JP355, JP357, JP362, JP363, JP364, JP365, JP366, JP367, JP368, JP369, JP381, JP383, JP385, JP387, JP392, JP393, JP394, JP395, JP396, JP397, JP398, JP399, JP411, JP413, JP415, JP417, JP422, JP423, JP424, JP425, JP426, JP427, JP428, JP429, JP441, JP443, JP445, JP447: 1X01_ALLIGATOR_3MM_HALF
JP3, JP5, JP7, JP9, JP11, JP13, JP17, JP19, JP21, JP23, JP25, JP27, JP28, JP41, JP42, JP43, JP44, JP45, JP46, JP47, JP48, JP50, JP52, JP54, JP56, JP58, JP71, JP72, JP73, JP74, JP75, JP76, JP77, JP78, JP80, JP82, JP84, JP86, JP88, JP101, JP102, JP103, JP104, JP105, JP106, JP107, JP108, JP110, JP112, JP114, JP116, JP118, JP131, JP132, JP133, JP134, JP135, JP136, JP137, JP138, JP140, JP142, JP144, JP146, JP148, JP161, JP162, JP163, JP164, JP165, JP166, JP167, JP168, JP170, JP172, JP174, JP176, JP178, JP191, JP192, JP193, JP194, JP195, JP196, JP197, JP198, JP200, JP202, JP204, JP206, JP208, JP221, JP222, JP223, JP224, JP225, JP226, JP227, JP228, JP230, JP232, JP234, JP236, JP238, JP251, JP252, JP253, JP254, JP255, JP256, JP257, JP258, JP260, JP262, JP264, JP266, JP268, JP281, JP282, JP283, JP284, JP285, JP286, JP287, JP288, JP290, JP292, JP294, JP296, JP298, JP311, JP312, JP313, JP314, JP315, JP316, JP317, JP318, JP320, JP322, JP324, JP326, JP328, JP341, JP342, JP343, JP344, JP345, JP346, JP347, JP348, JP350, JP352, JP354, JP356, JP358, JP371, JP372, JP373, JP374, JP375, JP376, JP377, JP378, JP380, JP382, JP384, JP386, JP388, JP401, JP402, JP403, JP404, JP405, JP406, JP407, JP408, JP410, JP412, JP414, JP416, JP418, JP431, JP432, JP433, JP434, JP435, JP436, JP437, JP438, JP440, JP442, JP444, JP446, JP448: 1X01_NO_SILK
JP14, JP40, JP70, JP100, JP130, JP160, JP190, JP220, JP250, JP280, JP310, JP340, JP370, JP400, JP430: JST-3-PTH-VERT
JP15, JP31, JP61, JP91, JP121, JP151, JP181, JP211, JP241, JP271, JP301, JP331, JP361, JP391, JP421: USB-B-MICRO-SMD_V03
JP29, JP60, JP90, JP120, JP150, JP180, JP210, JP240, JP270, JP300, JP330, JP360, JP390, JP420, JP450: JST-4-PTH-VERT
JP30, JP59, JP89, JP119, JP149, JP179, JP209, JP239, JP269, JP299, JP329, JP359, JP389, JP419, JP449: 1X04_NO_SILK
L1, L2, L3, L4, L5, L6, L7, L8, L9, L10, L11, L12, L13, L14, L15, L16, L17, L18, L19, L20, L21, L22, L23, L24, L25, L26, L27, L28, L29, L30: DNP; 0603
LOGO1, LOGO4, LOGO7, LOGO10, LOGO13, LOGO16, LOGO19, LOGO22, LOGO25, LOGO28, LOGO31, LOGO34, LOGO37, LOGO40, LOGO43: SFE_LOGO_NAME.2_INCH; SFE_LOGO_NAME_.2
LOGO2, LOGO5, LOGO8, LOGO11, LOGO14, LOGO17, LOGO20, LOGO23, LOGO26, LOGO29, LOGO32, LOGO35, LOGO38, LOGO41, LOGO44: OSHW-LOGOS; OSHW-LOGO-S
LOGO3, LOGO6, LOGO9, LOGO12, LOGO15, LOGO18, LOGO21, LOGO24, LOGO27, LOGO30, LOGO33, LOGO36, LOGO39, LOGO42, LOGO45: SFE_LOGO_NAME.3_INCH; SFE_LOGO_NAME_.3
Q1, Q6, Q9, Q12, Q15, Q18, Q21, Q24, Q27, Q30, Q33, Q36, Q39, Q42, Q45: 2.5A/30V; SOT23-3
Q2, Q3, Q4, Q5, Q7, Q8, Q10, Q11, Q13, Q14, Q16, Q17, Q19, Q20, Q22, Q23, Q25, Q26, Q28, Q29, Q31, Q32, Q34, Q35, Q37, Q38, Q40, Q41, Q43, Q44: MMBT2222A; SOT23-3@1
R1, R21, R41, R61, R81, R101, R121, R141, R161, R181, R201, R221, R241, R261, R281: 12k; 0603-RES
R2, R12, R37, R38, R57, R58, R77, R78, R97, R98, R117, R118, R137, R138, R157, R158, R177, R178, R197, R198, R217, R218, R237, R238, R257, R258, R277, R278, R297, R298: 1K; 0603-RES
R3, R33, R53, R73, R93, R113, R133, R153, R173, R193, R213, R233, R253, R273, R293: 22K; 0603-RES
R4, R34, R54, R74, R94, R114, R134, R154, R174, R194, R214, R234, R254, R274, R294: 10K; 0603-RES
R5, R40, R60, R80, R100, R120, R140, R160, R180, R200, R220, R240, R260, R280, R300: DNP; 1/6W-RES
R6, R39, R59, R79, R99, R119, R139, R159, R179, R199, R219, R239, R259, R279, R299: 2.0k; 0603-RES
R7, R8, R10, R17, R18, R19, R20, R22, R23, R24, R25, R27, R30, R36, R42, R43, R44, R45, R47, R50, R56, R62, R63, R64, R65, R67, R70, R76, R82, R83, R84, R85, R87, R90, R96, R102, R103, R104, R105, R107, R110, R116, R122, R123, R124, R125, R127, R130, R136, R142, R143, R144, R145, R147, R150, R156, R162, R163, R164, R165, R167, R170, R176, R182, R183, R184, R185, R187, R190, R196, R202, R203, R204, R205, R207, R210, R216, R222, R223, R224, R225, R227, R230, R236, R242, R243, R244, R245, R247, R250, R256, R262, R263, R264, R265, R267, R270, R276, R282, R283, R284, R285, R287, R290, R296: 10K; 0603-RES@1
R9, R26, R46, R66, R86, R106, R126, R146, R166, R186, R206, R226, R246, R266, R286: 200; 0603-RES
R11, R35, R55, R75, R95, R115, R135, R155, R175, R195, R215, R235, R255, R275, R295: 330; 0603-RES
R13, R14, R28, R29, R48, R49, R68, R69, R88, R89, R108, R109, R128, R129, R148, R149, R168, R169, R188, R189, R208, R209, R228, R229, R248, R249, R268, R269, R288, R289: 27; 0603-RES
R15, R16, R31, R32, R51, R52, R71, R72, R91, R92, R111, R112, R131, R132, R151, R152, R171, R172, R191, R192, R211, R212, R231, R232, R251, R252, R271, R272, R291, R292: 4.7K; 0603-RES
S1, S2, S3, S4, S5, S6, S7, S8, S9, S10, S11, S12, S13, S14, S15: TACTILE-SWITCH-SMD
SJ1, SJ6, SJ10, SJ14, SJ18, SJ22, SJ26, SJ30, SJ34, SJ38, SJ42, SJ46, SJ50, SJ54, SJ58: PAD-JUMPER-2-NC_BY_TRACE_YES_SILK
SJ2, SJ5, SJ9, SJ13, SJ17, SJ21, SJ25, SJ29, SJ33, SJ37, SJ41, SJ45, SJ49, SJ53, SJ57: PWRLED; PAD-JUMPER-2-NC_BY_TRACE_YES_SILK
SJ3, SJ8, SJ12, SJ16, SJ20, SJ24, SJ28, SJ32, SJ36, SJ40, SJ44, SJ48, SJ52, SJ56, SJ60: WS2812-VCC; PAD-JUMPER-2-NC_BY_TRACE_YES_SILK
SJ4, SJ7, SJ11, SJ15, SJ19, SJ23, SJ27, SJ31, SJ35, SJ39, SJ43, SJ47, SJ51, SJ55, SJ59: PAD-JUMPER-3-3OF3_NC_BY_TRACE_YES_SILK_FULL_BOX
STANDOFF1, STANDOFF2, STANDOFF3, STANDOFF4, STANDOFF5, STANDOFF6, STANDOFF7, STANDOFF8, STANDOFF9, STANDOFF10, STANDOFF11, STANDOFF12, STANDOFF13, STANDOFF14, STANDOFF15, STANDOFF16, STANDOFF17, STANDOFF18, STANDOFF19, STANDOFF20, STANDOFF21, STANDOFF22, STANDOFF23, STANDOFF24, STANDOFF25, STANDOFF26, STANDOFF27, STANDOFF28, STANDOFF29, STANDOFF30, STANDOFF31, STANDOFF32, STANDOFF33, STANDOFF34, STANDOFF35, STANDOFF36, STANDOFF37, STANDOFF38, STANDOFF39, STANDOFF40, STANDOFF41, STANDOFF42, STANDOFF43, STANDOFF44, STANDOFF45, STANDOFF46, STANDOFF47, STANDOFF48, STANDOFF49, STANDOFF50, STANDOFF51, STANDOFF52, STANDOFF53, STANDOFF54, STANDOFF55, STANDOFF56, STANDOFF57, STANDOFF58, STANDOFF59, STANDOFF60: STAND-OFF
U1, U11, U17, U23, U29, U35, U41, U47, U53, U59, U65, U71, U77, U83, U89: MCP73831; SOT23-5
U2, U7, U13, U19, U25, U31, U37, U43, U49, U55, U61, U67, U73, U79, U85: ESP8266; QFN32
U3, U12, U18, U24, U30, U36, U42, U48, U54, U60, U66, U72, U78, U84, U90: AP2112K-3.3V; SOT23-5
U4, U9, U15, U21, U27, U33, U39, U45, U51, U57, U63, U69, U75, U81, U87: FT231XS-U; SSOP20_L
U5, U8, U14, U20, U26, U32, U38, U44, U50, U56, U62, U68, U74, U80, U86: W25Q32FVSS; SOIC-8
U6, U10, U16, U22, U28, U34, U40, U46, U52, U58, U64, U70, U76, U82, U88: SI7021
Y1, Y2, Y3, Y4, Y5, Y6, Y7, Y8, Y9, Y10, Y11, Y12, Y13, Y14, Y15: 26MHz; CRYSTAL-SMD-3.2X2.5

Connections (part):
0/BUTTON: JP26.1@2, JP27.1, Q3.3, R19.1, S1.1, S1.2, U2.15
0/BUTTON1: JP55.1@2, JP56.1, Q5.3, R23.1, S2.1, S2.2, U7.15
0/BUTTON2: JP85.1@2, JP86.1, Q8.3, R43.1, S3.1, S3.2, U13.15
0/BUTTON3: JP115.1@2, JP116.1, Q11.3, R63.1, S4.1, S4.2, U19.15
0/BUTTON4: JP145.1@2, JP146.1, Q14.3, R83.1, S5.1, S5.2, U25.15
0/BUTTON5: JP175.1@2, JP176.1, Q17.3, R103.1, S6.1, S6.2, U31.15
0/BUTTON6: JP205.1@2, JP206.1, Q20.3, R123.1, S7.1, S7.2, U37.15
0/BUTTON7: JP235.1@2, JP236.1, Q23.3, R143.1, S8.1, S8.2, U43.15
0/BUTTON8: JP265.1@2, JP266.1, Q26.3, R163.1, S9.1, S9.2, U49.15
0/BUTTON9: JP295.1@2, JP296.1, Q29.3, R183.1, S10.1, S10.2, U55.15
0/BUTTON10: JP325.1@2, JP326.1, Q32.3, R203.1, S11.1, S11.2, U61.15
0/BUTTON11: JP355.1@2, JP356.1, Q35.3, R223.1, S12.1, S12.2, U67.15
0/BUTTON12: JP385.1@2, JP386.1, Q38.3, R243.1, S13.1, S13.2, U73.15
0/BUTTON13: JP415.1@2, JP416.1, Q41.3, R263.1, S14.1, S14.2, U79.15
0/BUTTON14: JP445.1@2, JP446.1, Q44.3, R283.1, S15.1, S15.2, U85.15
2/SDA: JP29.1, JP30.3, R15.1, U2.14, U6.DATA
2/SDA1: JP59.3, JP60.1, R31.1, U7.14, U10.DATA
2/SDA2: JP89.3, JP90.1, R51.1, U13.14, U16.DATA
2/SDA3: JP119.3, JP120.1, R71.1, U19.14, U22.DATA
2/SDA4: JP149.3, JP150.1, R91.1, U25.14, U28.DATA
2/SDA5: JP179.3, JP180.1, R111.1, U31.14, U34.DATA
2/SDA6: JP209.3, JP210.1, R131.1, U37.14, U40.DATA
2/SDA7: JP239.3, JP240.1, R151.1, U43.14, U46.DATA
2/SDA8: JP269.3, JP270.1, R171.1, U49.14, U52.DATA
2/SDA9: JP299.3, JP300.1, R191.1, U55.14, U58.DATA
2/SDA10: JP329.3, JP330.1, R211.1, U61.14, U64.DATA
2/SDA11: JP359.3, JP360.1, R231.1, U67.14, U70.DATA
2/SDA12: JP389.3, JP390.1, R251.1, U73.14, U76.DATA
2/SDA13: JP419.3, JP420.1, R271.1, U79.14, U82.DATA
2/SDA14: JP449.3, JP450.1, R291.1, U85.14, U88.DATA
3.3V_F: C16.1, U4.3, U4.13, U4.14
3.3V_F1: C24.1, U9.3, U9.13, U9.14
3.3V_F2: C43.1, U15.3, U15.13, U15.14
3.3V_F3: C62.1, U21.3, U21.13, U21.14
3.3V_F4: C81.1, U27.3, U27.13, U27.14
3.3V_F5: C100.1, U33.3, U33.13, U33.14
3.3V_F6: C119.1, U39.3, U39.13, U39.14
3.3V_F7: C138.1, U45.3, U45.13, U45.14
3.3V_F8: C157.1, U51.3, U51.13, U51.14
3.3V_F9: C176.1, U57.3, U57.13, U57.14
3.3V_F10: C195.1, U63.3, U63.13, U63.14
3.3V_F11: C214.1, U69.3, U69.13, U69.14
3.3V_F12: C233.1, U75.3, U75.13, U75.14
3.3V_F13: C252.1, U81.3, U81.13, U81.14
3.3V_F14: C271.1, U87.3, U87.13, U87.14
4/WS1: D6.4, U7.16
4/WS2: D11.4, U13.16
4/WS3: D16.4, U19.16
4/WS4: D21.4, U25.16
4/WS5: D26.4, U31.16
4/WS6: D31.4, U37.16
4/WS7: D36.4, U43.16
4/WS8: D41.4, U49.16
4/WS9: D46.4, U55.16
4/WS10: D51.4, U61.16
4/WS11: D56.4, U67.16
4/WS12: D61.4, U73.16
4/WS13: D66.4, U79.16
4/WS14: D71.4, U85.16
4/WS2812: D4.4, U2.16
14/SCL: JP29.4, JP30.4, R16.1, U2.9, U6.SCK
14/SCL1: JP59.4, JP60.4, R32.1, U7.9, U10.SCK
14/SCL2: JP89.4, JP90.4, R52.1, U13.9, U16.SCK
14/SCL3: JP119.4, JP120.4, R72.1, U19.9, U22.SCK
14/SCL4: JP149.4, JP150.4, R92.1, U25.9, U28.SCK
14/SCL5: JP179.4, JP180.4, R112.1, U31.9, U34.SCK
14/SCL6: JP209.4, JP210.4, R132.1, U37.9, U40.SCK
14/SCL7: JP239.4, JP240.4, R152.1, U43.9, U46.SCK
14/SCL8: JP269.4, JP270.4, R172.1, U49.9, U52.SCK
14/SCL9: JP299.4, JP300.4, R192.1, U55.9, U58.SCK
14/SCL10: JP329.4, JP330.4, R212.1, U61.9, U64.SCK
14/SCL11: JP359.4, JP360.4, R232.1, U67.9, U70.SCK
14/SCL12: JP389.4, JP390.4, R252.1, U73.9, U76.SCK
14/SCL13: JP419.4, JP420.4, R272.1, U79.9, U82.SCK
14/SCL14: JP449.4, JP450.4, R292.1, U85.9, U88.SCK
ADC: IC1.6, IC1.7, U2.6
ADC1: IC2.6, IC2.7, U7.6
ADC2: IC3.6, IC3.7, U13.6
ADC3: IC4.6, IC4.7, U19.6
ADC4: IC5.6, IC5.7, U25.6
ADC5: IC6.6, IC6.7, U31.6
ADC6: IC7.6, IC7.7, U37.6
ADC7: IC8.6, IC8.7, U43.6
ADC8: IC9.6, IC9.7, U49.6
ADC9: IC10.6, IC10.7, U55.6
ADC10: IC11.6, IC11.7, U61.6
ADC11: IC12.6, IC12.7, U67.6
ADC12: IC13.6, IC13.7, U73.6
ADC13: IC14.6, IC14.7, U79.6
ADC14: IC15.6, IC15.7, U85.6
ADC-IN: IC1.3, JP20.1@2, JP21.1
ADC-IN1: IC2.3, JP37.1@2, JP42.1
ADC-IN2: IC3.3, JP67.1@2, JP72.1
ADC-IN3: IC4.3, JP97.1@2, JP102.1
ADC-IN4: IC5.3, JP127.1@2, JP132.1
ADC-IN5: IC6.3, JP157.1@2, JP162.1
ADC-IN6: IC7.3, JP187.1@2, JP192.1
ADC-IN7: IC8.3, JP217.1@2, JP222.1
ADC-IN8: IC9.3, JP247.1@2, JP252.1
ADC-IN9: IC10.3, JP277.1@2, JP282.1
ADC-IN10: IC11.3, JP307.1@2, JP312.1
ADC-IN11: IC12.3, JP337.1@2, JP342.1
ADC-IN12: IC13.3, JP367.1@2, JP372.1
ADC-IN13: IC14.3, JP397.1@2, JP402.1
ADC-IN14: IC15.3, JP427.1@2, JP432.1
CHIP_EN: R8.1, U2.7
CHIP_EN1: R25.1, U7.7
CHIP_EN2: R45.1, U13.7
CHIP_EN3: R65.1, U19.7
CHIP_EN4: R85.1, U25.7
CHIP_EN5: R105.1, U31.7
CHIP_EN6: R125.1, U37.7
CHIP_EN7: R145.1, U43.7
CHIP_EN8: R165.1, U49.7
CHIP_EN9: R185.1, U55.7
CHIP_EN10: R205.1, U61.7
CHIP_EN11: R225.1, U67.7
CHIP_EN12: R245.1, U73.7
CHIP_EN13: R265.1, U79.7
CHIP_EN14: R285.1, U85.7
D+: C13.1, JP15.D+, R14.1
D+1: C22.1, JP31.D+, R29.1
D+2: C41.1, JP61.D+, R49.1
D+3: C60.1, JP91.D+, R69.1
D+4: C79.1, JP121.D+, R89.1
D+5: C98.1, JP151.D+, R109.1
D+6: C117.1, JP181.D+, R129.1
D+7: C136.1, JP211.D+, R149.1
D+8: C155.1, JP241.D+, R169.1
D+9: C174.1, JP271.D+, R189.1
D+10: C193.1, JP301.D+, R209.1
D+11: C212.1, JP331.D+, R229.1
D+12: C231.1, JP361.D+, R249.1
D+13: C250.1, JP391.D+, R269.1
D+14: C269.1, JP421.D+, R289.1
D-: C12.1, JP15.D-, R13.1
D-1: C30.1, JP31.D-, R28.1
D-2: C49.1, JP61.D-, R48.1
D-3: C68.1, JP91.D-, R68.1
D-4: C87.1, JP121.D-, R88.1
D-5: C106.1, JP151.D-, R108.1
D-6: C125.1, JP181.D-, R128.1
D-7: C144.1, JP211.D-, R148.1
D-8: C163.1, JP241.D-, R168.1
D-9: C182.1, JP271.D-, R188.1
D-10: C201.1, JP301.D-, R208.1
D-11: C220.1, JP331.D-, R228.1
D-12: C239.1, JP361.D-, R248.1
D-13: C258.1, JP391.D-, R268.1
D-14: C277.1, JP421.D-, R288.1
DTR: Q3.2, R17.1, U4.1
DTR1: Q5.2, R30.1, U9.1
DTR2: Q8.2, R50.1, U15.1
DTR3: Q11.2, R70.1, U21.1
DTR4: Q14.2, R90.1, U27.1
DTR5: Q17.2, R110.1, U33.1
DTR6: Q20.2, R130.1, U39.1
DTR7: Q23.2, R150.1, U45.1
DTR8: Q26.2, R170.1, U51.1
DTR9: Q29.2, R190.1, U57.1
DTR10: Q32.2, R210.1, U63.1
DTR11: Q35.2, R230.1, U69.1
DTR12: Q38.2, R250.1, U75.1
DTR13: Q41.2, R270.1, U81.1
DTR14: Q44.2, R290.1, U87.1
GND: C1.2, C2.2, C3.1, C4.1, C5.2, C6.2, C7.2, C9.2, C10.2, C11.2, C12.2, C13.2, C14.2, C15.2, C16.2, C17.2, C18.2, C19.2, D4.3, E1.GND, E1.GND2, IC1.4, JP1.1, JP6.1@2, JP7.1, JP14.2, JP15.GND, JP29.3, JP30.1, L1.2, L2.2, R1.1, R4.1, R5.1, R6.1, R7.1, R11.2, R20.1, S1.3, S1.4, SJ2.1, U1.2, U2.EP, U3.2, U4.6, U4.16, U5.4, U6.GND, Y1.2, Y1.4
GND1: C20.2, C21.2, C22.2, C23.2, C24.2, C25.2, C26.1, C27.1, C29.2, C30.2, C31.2, C32.2, C33.2, C34.2, C35.2, C36.2, C37.2, C38.2, D6.3, E2.GND, E2.GND2, IC2.4, JP31.GND, JP39.1@2, JP40.2, JP44.1, JP49.1, JP59.1, JP60.3, L3.2, L4.2, R21.1, R24.1, R34.1, R35.2, R36.1, R39.1, R40.1, S2.3, S2.4, SJ5.1, U7.EP, U8.4, U9.6, U9.16, U10.GND, U11.2, U12.2, Y2.2, Y2.4
GND2: C39.2, C40.2, C41.2, C42.2, C43.2, C44.2, C45.1, C46.1, C48.2, C49.2, C50.2, C51.2, C52.2, C53.2, C54.2, C55.2, C56.2, C57.2, D11.3, E3.GND, E3.GND2, IC3.4, JP61.GND, JP69.1@2, JP70.2, JP74.1, JP79.1, JP89.1, JP90.3, L5.2, L6.2, R41.1, R44.1, R54.1, R55.2, R56.1, R59.1, R60.1, S3.3, S3.4, SJ9.1, U13.EP, U14.4, U15.6, U15.16, U16.GND, U17.2, U18.2, Y3.2, Y3.4
GND3: C58.2, C59.2, C60.2, C61.2, C62.2, C63.2, C64.1, C65.1, C67.2, C68.2, C69.2, C70.2, C71.2, C72.2, C73.2, C74.2, C75.2, C76.2, D16.3, E4.GND, E4.GND2, IC4.4, JP91.GND, JP99.1@2, JP100.2, JP104.1, JP109.1, JP119.1, JP120.3, L7.2, L8.2, R61.1, R64.1, R74.1, R75.2, R76.1, R79.1, R80.1, S4.3, S4.4, SJ13.1, U19.EP, U20.4, U21.6, U21.16, U22.GND, U23.2, U24.2, Y4.2, Y4.4
GND4: C77.2, C78.2, C79.2, C80.2, C81.2, C82.2, C83.1, C84.1, C86.2, C87.2, C88.2, C89.2, C90.2, C91.2, C92.2, C93.2, C94.2, C95.2, D21.3, E5.GND, E5.GND2, IC5.4, JP121.GND, JP129.1@2, JP130.2, JP134.1, JP139.1, JP149.1, JP150.3, L9.2, L10.2, R81.1, R84.1, R94.1, R95.2, R96.1, R99.1, R100.1, S5.3, S5.4, SJ17.1, U25.EP, U26.4, U27.6, U27.16, U28.GND, U29.2, U30.2, Y5.2, Y5.4
GND5: C96.2, C97.2, C98.2, C99.2, C100.2, C101.2, C102.1, C103.1, C105.2, C106.2, C107.2, C108.2, C109.2, C110.2, C111.2, C112.2, C113.2, C114.2, D26.3, E6.GND, E6.GND2, IC6.4, JP151.GND, JP159.1@2, JP160.2, JP164.1, JP169.1, JP179.1, JP180.3, L11.2, L12.2, R101.1, R104.1, R114.1, R115.2, R116.1, R119.1, R120.1, S6.3, S6.4, SJ21.1, U31.EP, U32.4, U33.6, U33.16, U34.GND, U35.2, U36.2, Y6.2, Y6.4
GND6: C115.2, C116.2, C117.2, C118.2, C119.2, C120.2, C121.1, C122.1, C124.2, C125.2, C126.2, C127.2, C128.2, C129.2, C130.2, C131.2, C132.2, C133.2, D31.3, E7.GND, E7.GND2, IC7.4, JP181.GND, JP189.1@2, JP190.2, JP194.1, JP199.1, JP209.1, JP210.3, L13.2, L14.2, R121.1, R124.1, R134.1, R135.2, R136.1, R139.1, R140.1, S7.3, S7.4, SJ25.1, U37.EP, U38.4, U39.6, U39.16, U40.GND, U41.2, U42.2, Y7.2, Y7.4
GND7: C134.2, C135.2, C136.2, C137.2, C138.2, C139.2, C140.1, C141.1, C143.2, C144.2, C145.2, C146.2, C147.2, C148.2, C149.2, C150.2, C151.2, C152.2, D36.3, E8.GND, E8.GND2, IC8.4, JP211.GND, JP219.1@2, JP220.2, JP224.1, JP229.1, JP239.1, JP240.3, L15.2, L16.2, R141.1, R144.1, R154.1, R155.2, R156.1, R159.1, R160.1, S8.3, S8.4, SJ29.1, U43.EP, U44.4, U45.6, U45.16, U46.GND, U47.2, U48.2, Y8.2, Y8.4
GND8: C153.2, C154.2, C155.2, C156.2, C157.2, C158.2, C159.1, C160.1, C162.2, C163.2, C164.2, C165.2, C166.2, C167.2, C168.2, C169.2, C170.2, C171.2, D41.3, E9.GND, E9.GND2, IC9.4, JP241.GND, JP249.1@2, JP250.2, JP254.1, JP259.1, JP269.1, JP270.3, L17.2, L18.2, R161.1, R164.1, R174.1, R175.2, R176.1, R179.1, R180.1, S9.3, S9.4, SJ33.1, U49.EP, U50.4, U51.6, U51.16, U52.GND, U53.2, U54.2, Y9.2, Y9.4
GND9: C172.2, C173.2, C174.2, C175.2, C176.2, C177.2, C178.1, C179.1, C181.2, C182.2, C183.2, C184.2, C185.2, C186.2, C187.2, C188.2, C189.2, C190.2, D46.3, E10.GND, E10.GND2, IC10.4, JP271.GND, JP279.1@2, JP280.2, JP284.1, JP289.1, JP299.1, JP300.3, L19.2, L20.2, R181.1, R184.1, R194.1, R195.2, R196.1, R199.1, R200.1, S10.3, S10.4, SJ37.1, U55.EP, U56.4, U57.6, U57.16, U58.GND, U59.2, U60.2, Y10.2, Y10.4
GND10: C191.2, C192.2, C193.2, C194.2, C195.2, C196.2, C197.1, C198.1, C200.2, C201.2, C202.2, C203.2, C204.2, C205.2, C206.2, C207.2, C208.2, C209.2, D51.3, E11.GND, E11.GND2, IC11.4, JP301.GND, JP309.1@2, JP310.2, JP314.1, JP319.1, JP329.1, JP330.3, L21.2, L22.2, R201.1, R204.1, R214.1, R215.2, R216.1, R219.1, R220.1, S11.3, S11.4, SJ41.1, U61.EP, U62.4, U63.6, U63.16, U64.GND, U65.2, U66.2, Y11.2, Y11.4
GND11: C210.2, C211.2, C212.2, C213.2, C214.2, C215.2, C216.1, C217.1, C219.2, C220.2, C221.2, C222.2, C223.2, C224.2, C225.2, C226.2, C227.2, C228.2, D56.3, E12.GND, E12.GND2, IC12.4, JP331.GND, JP339.1@2, JP340.2, JP344.1, JP349.1, JP359.1, JP360.3, L23.2, L24.2, R221.1, R224.1, R234.1, R235.2, R236.1, R239.1, R240.1, S12.3, S12.4, SJ45.1, U67.EP, U68.4, U69.6, U69.16, U70.GND, U71.2, U72.2, Y12.2, Y12.4
GND12: C229.2, C230.2, C231.2, C232.2, C233.2, C234.2, C235.1, C236.1, C238.2, C239.2, C240.2, C241.2, C242.2, C243.2, C244.2, C245.2, C246.2, C247.2, D61.3, E13.GND, E13.GND2, IC13.4, JP361.GND, JP369.1@2, JP370.2, JP374.1, JP379.1, JP389.1, JP390.3, L25.2, L26.2, R241.1, R244.1, R254.1, R255.2, R256.1, R259.1, R260.1, S13.3, S13.4, SJ49.1, U73.EP, U74.4, U75.6, U75.16, U76.GND, U77.2, U78.2, Y13.2, Y13.4
GND13: C248.2, C249.2, C250.2, C251.2, C252.2, C253.2, C254.1, C255.1, C257.2, C258.2, C259.2, C260.2, C261.2, C262.2, C263.2, C264.2, C265.2, C266.2, D66.3, E14.GND, E14.GND2, IC14.4, JP391.GND, JP399.1@2, JP400.2, JP404.1, JP409.1, JP419.1, JP420.3, L27.2, L28.2, R261.1, R264.1, R274.1, R275.2, R276.1, R279.1, R280.1, S14.3, S14.4, SJ53.1, U79.EP, U80.4, U81.6, U81.16, U82.GND, U83.2, U84.2, Y14.2, Y14.4
GND14: C267.2, C268.2, C269.2, C270.2, C271.2, C272.2, C273.1, C274.1, C276.2, C277.2, C278.2, C279.2, C280.2, C281.2, C282.2, C283.2, C284.2, C285.2, D71.3, E15.GND, E15.GND2, IC15.4, JP421.GND, JP429.1@2, JP430.2, JP434.1, JP439.1, JP449.1, JP450.3, L29.2, L30.2, R281.1, R284.1, R294.1, R295.2, R296.1, R299.1, R300.1, S15.3, S15.4, SJ57.1, U85.EP, U86.4, U87.6, U87.16, U88.GND, U89.2, U90.2, Y15.2, Y15.4
GPIO1: D7.A, JP36.1@2, JP41.1, U7.24
GPIO2: JP35.1@2, JP45.1, U7.8
GPIO3: JP34.1@2, JP46.1, R24.2, U7.13
GPIO4: JP33.1@2, JP47.1, U7.12
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

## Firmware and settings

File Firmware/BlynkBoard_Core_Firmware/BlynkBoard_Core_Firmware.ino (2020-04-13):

/******************************************************************************
BlynkBoard_Core_Firmware.ino
BlynkBoard Firmware: Main Source
Jim Lindblom @ SparkFun Electronics
February 24, 2016
https://github.com/sparkfun/Blynk_Board_ESP8266/Firmware

This file, part of the BlynkBoard Firmware, is the top-level source code.
It includes the main loop() and setup() function. It also maintains the
WS2812 status LED

Resources:
ESP8266WiFi Library (included with ESP8266 Arduino board definitions)
ESP8266WiFiClient Library (included with ESP8266 Arduino board definitions)
ESP8266WebServer Library (included with ESP8266 Arduino board definitions)
Adafruit_NeoPixel Library - https://github.com/adafruit/Adafruit_NeoPixel

License:
This is released under the MIT license (http://opensource.org/licenses/MIT).
Please see the included LICENSE.md for more information.

Development environment specifics:
Arduino IDE 1.6.7
SparkFun BlynkBoard - ESP8266
ESP8266 Arduino Core - version 2.6.0 and above <- Critical, must be up-to-date
******************************************************************************/

//#define DEBUG_ENABLED
//#define SELF_TEST_ENABLED      //this is used for SparkFun's Production for QC tests
//#define CAPTIVE_PORTAL_ENABLE

#include "BlynkBoard_settings.h"
#include <ESP8266WiFi.h>
#include <WiFiClient.h>
#include <ESP8266WebServer.h>
#include <Adafruit_NeoPixel.h>   // http://librarymanager/All#neopixel
#include <Ticker.h>
#include <BlynkSimpleEsp8266.h>  // http://librarymanager/All#blynk
#include <EEPROM.h>
#include "FS.h"
#include <DNSServer.h>

/////////////////////////
// Function Prototypes //
/////////////////////////
// BlynkBoard_ConfigMode functions:
void handleRoot(void);
void handleReset(void);
void handleBoardInfo(void);
void handleConfig(void);
void setupServer(void);
void generateSSIDSuffix(bool newSSID);
void handleConfigServer(void);
void checkForStations(void);
bool setupAP(char * ssidName);
void checkSerialConfig(void);
void executeSerialCommand(void);
uint32_t rgbModeSelfTest(void);

// BlynkBoard_BlynkMode functions:
void buttonUpdate(void);
void blynkSetup(void);
void blynkLoop(void);

// BlynkBoard_setup functions:
bool initHardware(void);
bool checkConfigFlag(void);
bool checkFailAPSetupFlag(void);
void writeAPSetupFlag(bool pass);
bool writeBlynkConfig(String authToken, String host, uint16_t port);
String getBlynkAuth(void);
String getBlynkHost(void);
int16_t getBlynkPort(void);
int8_t setupBlynkStation(String network, String psk, 
                         String blynkAuth, 
                         String blynkHost = BB_BLYNK_HOST_DEFAULT,
                         uint16_t blynkPort = BB_BLYNK_PORT_DEFAULT);
void resetEEPROM(void);
long WiFiConnectWithTimeout(unsigned long timeout);
long BlynkConnectWithTimeout(const char * blynkAuth, const char * blynkDomain = BB_BLYNK_HOST_DEFAULT,
                             uint16_t blynkPort = BB_BLYNK_PORT_DEFAULT,
                             unsigned long timeout = BLYNK_CONNECT_TIMEOUT);
bool checkSelfTestFlag(void);
bool setSelfTestFlag(void);
void performSelfTest(void);

// BlynkBoard_Core_Firmware functions:
void buttonRelease(void);
void buttonChange(void);
void blinkRGBTimer(void);
void setRGB(uint32_t color);
uint32_t rgbModeConfig(void);
uint32_t blinkRGB(uint32_t onColor, uint32_t period);
uint32_t breatheRGB(uint32_t colorMax, unsigned int breathePeriod);

void setup()
{
  // runMode keeps track of the Blynk Board's current operating mode.
  // It may be either MODE_WAIT_CONFIG, MODE_CONFIG, MODE_CONFIG_DEVICE_CONNECTED,
  // MODE_CONNECTING_WIFI, MODE_CONNECTING_BLYNK, MODE_BLYNK_RUN,
  // or MODE_BLYNK_ERROR.
  
  // Initializes: Serial terminal, randomSeed, WS2812 RGB LED,
  // GP0 button, GP5 LED, SPIFFS (flash storage), and EEPROM.
  initHardware();
  
#ifdef SELF_TEST_ENABLED
  if (!checkSelfTestFlag())
  {
    BB_PRINT("Performing self test");
    runMode = MODE_SELF_TEST; // Set mode to control RGB LED
    // Self-test Will end in an infinite loop on either success or fail
    performSelfTest();
  }
#endif

  runMode = MODE_WAIT_CONFIG;
  previousMode = runMode; // Previous mode keeps track of the previous runMode
  
#ifdef DEBUG_ENABLED
  if (0 == digitalRead(BUTTON_PIN)) 
  {
    BB_DEBUG("Button pressed => reset config");
    resetEEPROM();
  }
#endif

  // Check if we're coming back from a 
  if (!checkFailAPSetupFlag())
  {
    BB_DEBUG("Failed to setup AP last time");
    runMode = MODE_CONFIG;
  }
  else if (checkConfigFlag()) // Checks EEPROM to determine if the Blynk/WiFi are configured
  { // If the flag has been set,
    g_blynkAuthStr = getBlynkAuth(); // read the stored auth token
    BB_PRINT("Auth token: " + g_blynkAuthStr);
    g_blynkHostStr = getBlynkHost(); // Read the stored host
    BB_PRINT("Blynk Host: " + g_blynkHostStr);
    g_blynkPort = getBlynkPort(); // Read the stored port
    BB_PRINT("Blynk Port: " + String(g_blynkPort));

    // As long as the auth token, host, and port aren't null
    if ((g_blynkAuthStr != 0) && (g_blynkHostStr != 0) && (g_blynkPort != 0))
    {
      // Connect to WiFi network stored in ESP8266's persistent flash
      if (WiFiConnectWithTimeout(WIFI_STA_CONNECT_TIMEOUT))
      { // If we successfully connect to WiFi, connect to Blynk
        BB_PRINT("Connected to WiFi!");
        if (BlynkConnectWithTimeout(g_blynkAuthStr.c_str(), g_blynkHostStr.c_str(), 
                                    g_blynkPort, BLYNK_CONNECT_TIMEOUT))
        { // If we successfully connect to Blynk
          BB_PRINT("Connected to Blynk!");
          blynkSetup(); // Run the Blynk setup function [BlynkBoard_BlynkMode]
        }
      }
    }
    else
    {
      runMode = MODE_CONFIG;
    }
  }
  else
  {
    runMode = MODE_CONFIG;
  }
}

void loop()
{
  switch (runMode)
  {
  case MODE_SELF_TEST:
    break;
  case MODE_WAIT_CONFIG: // Do nothing, wait for GP0 button
    break;
  case MODE_CONFIG: // Config mode - no connected device
    checkForStations(); // Check for any new connected device
    checkSerialConfig(); // Check for serial config messages
    if (previousMode != MODE_CONFIG)
    {
      generateSSIDSuffix(false); // Start the AP with the persistent BlynkMe-CCCC SSID
      setupServer(); // Start the config server up:      
      previousMode = MODE_CONFIG;
      Serial.print(SERIAL_MESSAGE_HELP);
    }
    break;
  case MODE_CONFIG_DEVICE_CONNECTED: // Config mode - connected device
    checkForStations(); // Check if any stations disconnect
    handleConfigServer(); // Serve up the config webpage
    checkSerialConfig(); // Check for serial config messages
    break;
  case MODE_BLYNK_RUN: // Main Blynk Demo run mode
    if (previousMode != MODE_BLYNK_RUN) // If this is the first execution of BLYNK_RUN since a state change
    {
      previousMode = MODE_BLYNK_RUN; // previousMode is used by MODE_BLYNK_ERROR
    }
    Blynk.run();
    if (Blynk.connected()) // If Blynk is connected
    {
      blynkLoop(); // Do the blynkLoop [BlynkBoard_BlynkMode]
    }
    else
    {
      runMode = MODE_BLYNK_ERROR; // Otherwise switch to MODE_BLYNK_ERROR mode
      BB_DEBUG("Blynk Disconnected");
    }
    break;
  case MODE_BLYNK_ERROR: // Error connecting to Blynk
    if (previousMode != MODE_BLYNK_ERROR) // If we just got here
    {
      g_blynkAuthStr = getBlynkAuth(); // read the stored auth token
      g_blynkHostStr = getBlynkHost(); // Read the stored host
      g_blynkPort = getBlynkPort(); // Read the stored port
      Blynk.config(g_blynkAuthStr.c_str(), g_blynkHostStr.c_str(), g_blynkPort);
      blinker.attach_ms(1, blinkRGBTimer); // Turn on the RGB blink timer
      previousMode = MODE_BLYNK_ERROR; // Update previousMode so blink timer isn't re-called
    }
    Blynk.run(); // Try to do a Blynk run
    if (Blynk.connected()) // If it establishes a connection
    {
      runMode = MODE_BLYNK_RUN; // Change to Blynk Run mode
      BB_DEBUG("Blynk Connected");
    }
    break;
  default: // Modes not defined: MODE_CONNECTING_WIFI, MODE_CONNECTING_BLYNK
    break;
  }
}

// buttonRelease is called when a button has been held
// for BUTTON_HOLD_TIME_MIN (3s) and released
void buttonRelease(void)
{
  // A button press has different effects in different modes:
  switch (runMode)
  {
  case MODE_WAIT_CONFIG: // If we're in "wait for config mode"
    BB_DEBUG("Switching to config mode");
    previousMode = runMode;
    runMode = MODE_CONFIG; // A button release will switch to config mode
    break;
  case MODE_CONFIG: // If we're in config mode:
    BB_DEBUG("Generating a new SSID suffix");
    generateSSIDSuffix(true); // Create a new SSID suffix
    break;
  case MODE_CONNECTING_WIFI:
  case MODE_CONNECTING_BLYNK:
    BB_DEBUG("Switching to config mode");
    runMode = MODE_CONFIG;
    break;
  }  
}

/* Note: The SparkFun Blynk board add-on is now supported by 
 the ESP8266 Community! If you are installing the ESP8266
 board add-on v2.6.0+ and using an interrupt service routine,
 you must include `ICACHE_RAM_ATTR` before the function
 definition. In this case, buttonChange() is the ISR. */

ICACHE_RAM_ATTR void buttonChange(void)
{
  static unsigned long buttonPressTime = 0;
  if (digitalRead(BUTTON_PIN)) // Button rising - released
  {
    runMode = previousMode; // Leave button press mode
    blinkCount = 0;
    BB_DEBUG("Button released");
    
    if (runMode == MODE_SELF_TEST)
    {
      if (selfTestResult == SELF_TEST_SUCCESS_VALUE)
      {
        // Set selftest flag
        setSelfTestFlag();
        previousMode = runMode;
        runMode = MODE_CONFIG;
        generateSSIDSuffix(true); // Create a new SSID suffix
      }
    }
    else
    {
      unsigned long buttonHoldTime = millis() - buttonPressTime;
      if (buttonHoldTime >= BUTTON_HOLD_TIME_MIN)
      {
        // If the button has been held for minimum time (3s)
        // execute the button release code:
        buttonRelease();
      }
    }
  }
  else // Button falling - pressed
  {
    BB_DEBUG("Button pressed");
    buttonPressTime = millis(); // Log the press time
    if ((runMode == MODE_WAIT_CONFIG) || (runMode == MODE_CONFIG) ||
        (runMode == MODE_CONNECTING_WIFI) || (runMode == MODE_CONNECTING_BLYNK))
    { // If in config, wait-for-config mode, or trying to connect
      previousMode = runMode; // Store current mode
      runMode = MODE_BUTTON_HOLD; // set to button-hold mode
      blinkCount = 0; // Restart LED
    } 
  }
}

// This function is tied to the blinker Ticker. It will either blink or
// breathe the RGB LED, then re-set the Ticker to be called at either
// the same, or a new return time.
void blinkRGBTimer(void)
{
  uint32_t returnTime = 0;
  rgbSetByProject = false;
  switch (runMode)
  {
    case MODE_SELF_TEST:
      returnTime = rgbModeSelfTest();
      break;
    case MODE_WAIT_CONFIG: // Waiting for config mode, blink white:
      returnTime = blinkRGB(RGB_STATUS_MODE_WAIT_CONFIG, RGB_PERIOD_SELF_TEST);
      break;
    case MODE_CONFIG:
      returnTime = rgbModeConfig(); // Blink the unique RGBYP code
      break;
    case MODE_BUTTON_HOLD:
      returnTime = breatheRGB(RGB_STATUS_MODE_BUTTON_HOLD, RGB_PERIOD_BUTTON_HOLD);
      break;
    case MODE_CONFIG_DEVICE_CONNECTED: // Device connected in config mode, blink purple:
      returnTime = blinkRGB(RGB_STATUS_AP_MODE_DEVICE_ON, RGB_PERIOD_AP_DEVICE_ON);
      break;
    case MODE_CONNECTING_WIFI: // Connecting to a WiFi AP, blink green
      returnTime = blinkRGB(RGB_STATUS_CONNECTING_WIFI, RGB_PERIOD_CONNECTING);
      break;
    case MODE_CONNECTING_BLYNK: // Connecting to Blynk cloud, blink blue
      returnTime = blinkRGB(RGB_STATUS_CONNECTING_BLYNK, RGB_PERIOD_BLYNK_CONNECTING);
      break;
    case MODE_BLYNK_RUN: // In Blynk run mode, breathe blue
      returnTime = breatheRGB(RGB_STATUS_CONNECTED_BLYNK, RGB_PERIOD_RUNNING);
      break;
    case MODE_BLYNK_ERROR: // Error connecting to Blynk, blink yellow
      returnTime = blinkRGB(RGB_STATUS_CANT_CONNECT_BLYNK, RGB_PERIOD_BLINK_ERROR);
      break;
  }
  if (returnTime > 0) // Call this function again in returnTime ms
    blinker.attach_ms(returnTime, blinkRGBTimer);
}
// Blink the LED with a unique-ish combination of R/G/B/Y/P
// Returns a time, in ms, when this function should be called again
uint32_t rgbModeConfig(void)
{
  uint32_t retVal = 0;

  // Assume blinkCount is anywhere between 0-255
  // If it's greater than our suffix length (4) times two
  if (blinkCount >= SSID_SUFFIX_LENGTH * 2)
  {
    setRGB(WS2812_OFF); // Turn the LED off
    retVal = RGB_PERIOD_AP_STOP; // Come back in a longer time
    blinkCount = 0; // Reset blinkCount
  }
  else // If we're blinking a color, or mid-color
  {
    if (blinkCount % 2 == 0) // If even, blink the color
      setRGB(SSID_COLORS[ssidSuffixIndex[blinkCount / 2]]);
    else // If odd, turn the LED off
      setRGB(WS2812_OFF);
    retVal = RGB_PERIOD_AP / 2; // Come back in a shorter time
    blinkCount++; // Increment blinkCount
  }

  return retVal; // Return the blink time
}

// Continuously blink through r/g/b
uint32_t rgbModeSelfTest(void)
{
  if (blinkCount > 2) blinkCount = 0;
  
  if (blinkCount == 0) setRGB(0x200000); // Red
  else if (blinkCount == 1) setRGB(0x002000); // Green
  else if (blinkCount == 2) setRGB(0x000020); // Blue
    
  blinkCount++; // Increment blinkCount
  blinkCount %= 3; // Limit blinkCount range to 0-2
  return RGB_PERIOD_START;
}

// Blink the LED a specific color with a set period.
// 50% duty cycle ~ even on/off time.
// Returns a time, in ms, when this function should be called again
uint32_t blinkRGB(uint32_t onColor, uint32_t period)
{
  // Assume blinkCount is anywhere between 0-255
  if (blinkCount % 2 == 0) // If blinkCount is even (0)
  {
    setRGB(onColor); // Turn the LED on
    blinkCount = 1; // Turn the LED off next time
  }
  else // If blinkCount is odd (1)
  {
    setRGB(WS2812_OFF); // Turn LED off
    blinkCount = 0; // Turn the LED on next time
  }
  
  return period / 2; // Come back in half the period
}

// Breathe the LED between off and a maximum 32-bit color value
// Returns a time, in ms, when this function should be called again
uint32_t breatheRGB(uint32_t colorMax, unsigned int breathePeriod)
{
  // Find the three r/g/b colors from colorMax:
  uint8_t redMax = (colorMax & 0xFF0000) >> 16;
  uint8_t greenMax = (colorMax & 0x00FF00) >> 8;
  uint8_t blueMax = (colorMax & 0x0000FF);

  // Determine the color brightness, based on blinkCount.
  // brightness will steadily rise from 0 to 128, then steadily fall back to 0
  uint8_t brightness;
  if (blinkCount < 128) // If it's 0-128
    brightness = blinkCount; // Leave it be
  else // If it's 129->255
    brightness = 255 - blinkCount; // Adjust it to 127-0

  // Multiply our three colors by the brightness:
  redMax *= ((float)brightness / 128.0);
  greenMax *= ((float)brightness / 128.0);
  blueMax *= ((float)brightness / 128.0);
  // And turn the LED to that color:
  setRGB(rgb.Color(redMax, greenMax, blueMax));

  blinkCount++; // Increment blinkCount
  // This function relies on the 8-bit, unsigned blinkCount rolling over. 
  // If it's 255, it'll go back to 0.
  return breathePeriod / 256;
}

// All-in-one RGB-setting function
void setRGB(uint32_t color)
{
  rgb.setPixelColor(0, color);
  rgb.show();
}

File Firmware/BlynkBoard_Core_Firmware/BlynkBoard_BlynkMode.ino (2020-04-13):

/******************************************************************************
BlynkBoard_BlynkMode.ino
BlynkBoard Firmware: Blynk Demo Source
Jim Lindblom @ SparkFun Electronics
February 24, 2016
https://github.com/sparkfun/Blynk_Board_ESP8266/Firmware

This file, part of the BlynkBoard Firmware, implements all "Blynk Mode"
functions of the BlynkBoard Core Firmware. That includes managing the Blynk
connection and ~10 example experiments, which can be conducted without
reprogramming the Blynk Board.

 Supported Experiment list:
 0: RGB LED - ZeRGBa (V0)
 2: 5 LED - Button (D5)
 3: 0 Button - Virtual LED (V3)
      2~: 0 Button - tweet, would need to modify button interrupt handler
 4: Humidity and temperature to <strike>gauge</strike> value displays
 5: RGB control from <strike>Zebra widet</strike> Sliders
 6. Incoming serial on hardware port sends to terminal in Blynk
 7. ADC hooked to VIN pin on graph
 8. TODO: Alligator clips connected to GPIO 12(?) send an email
 9. TODO: Timer triggers relay
 10. TODO: IMU graphs to phone 

Resources:
Blynk Arduino Library: https://github.com/blynkkk/blynk-library/releases/tag/v0.3.1
SparkFun HTU21D Library: https://github.com/sparkfun/SparkFun_HTU21D_Breakout_Arduino_Library/releases/tag/V_1.1.1

License:
This is released under the MIT license (http://opensource.org/licenses/MIT).
Please see the included LICENSE.md for more information.

Development environment specifics:
Arduino IDE 1.6.7
SparkFun BlynkBoard - ESP8266
******************************************************************************/

#include <Wire.h>
#include "SparkFunHTU21D.h"
#include <SparkFunTSL2561.h>
#include "Servo.h"
HTU21D thSense;

bool scanI2C(uint8_t address);

////////////////////////////////////
// Blynk Virtual Variable Mapping //
//////////////////////////////////// // Experiment #(s)
#define RGB_VIRTUAL               V0 // 0, 6
#define BUTTON_VIRTUAL            V1 // 1
#define RED_VIRTUAL               V2 // 3
#define GREEN_VIRTUAL             V3 // 3
#define BLUE_VIRTUAL              V4 // 3
#define TEMPERATURE_F_VIRTUAL     V5 // 4
#define TEMPERATURE_C_VIRTUAL     V6 // 4
#define HUMIDITY_VIRTUAL          V7 // 4
#define ADC_VOLTAGE_VIRTUAL       V8 // 5
#define RGB_RAINBOW_VIRTUAL       V9 // 6
#define LCD_VIRTUAL               V10 // 8
#define LCD_TEMPHUMID_VIRTUAL     V11 // 8
#define LCD_STATS_VIRTUAL         V12 // 8
#define LCD_RUNTIME_VIRTUAL       V13 // 8
#define SERVO_XY_VIRTUAL          V14
#define RGB_MAX_BRIGHTNESS_VIRTUAL V15// 0, 6
#define SERVO_MAX_VIRTUAL         V16 // 9
#define SERVO_ANGLE_VIRTUAL       V17 // 9
#define LUX_VIRTUAL               V18 // 10
//! V19 available
#define ADC_BATT_VIRTUAL          V20 // 11
#define SERIAL_VIRTUAL            V21 // 12, 15
//! V22 available
#define TWITTER_THRESHOLD_VIRTUAL V23 // 13
#define TWITTER_RATE_VIRTUAL      V24 // 13
#define DOOR_STATE_VIRTUAL        V25 // 14
//! V26 available
#define EMAIL_ENABLED_VIRTUAL     V27 // 15
#define TEMP_OFFSET_VIRTUAL       V28 // 4
#define RGB_STRIP_NUM_VIRTUAL     V29 // 6
#define RUNTIME_VIRTUAL           V30 // Utility
#define RESET_VIRTUAL             V31 // Utility

WidgetLCD thLCD(LCD_VIRTUAL); // LCD widget, updated in blynkLoop
#define LCD_SPLASH_UPDATE_RATE 10000
unsigned long lastLCDSplashUpdate = 0;

// BLYNK_CONNECTED is called the first time the Blynk Board
// connects to Blynk. Then any time it reconnects later on.
bool firstConnect = true;
BLYNK_CONNECTED() 
{
  BB_DEBUG("Connected.");
  if (firstConnect)
  {
    BB_DEBUG("First connect.");
    // Print a message to the LCD the first time connecting.
    thLCD.print(0, 0, "sfe.io/blynk    ");
    thLCD.print(0, 1, "       for more!");
    
    firstConnect = false;
  }
  Blynk.syncAll(); // Sync all virtual variables
}

/* 0 0 0 0 0 0 0 0 0 0 0 0 0 0 0 0 0 0 0
 0 Experiment 0: zeRGBa                0
 0 Widget(s):                          0
 0  - zeRGBa: Merge, V0                0
 0 0 0 0 0 0 0 0 0 0 0 0 0 0 0 0 0 0 0 */
byte blynkRed = 0; // Keeps track of red value
byte blynkGreen = 0; // Keeps track of green value
byte blynkBlue = 0; // Keeps track of blue value
unsigned int rgbMaxBrightness = DEFAULT_MAX_BRIGHTNESS;

void updateBlynkRGB(void)
{
  if (!rgbSetByProject) // If the setByProject flag isn't set
  { // The LED should still be pulsing
    blinker.detach(); // Detach the rgbBlink timer
    rgbSetByProject = true; // Set the flag
  }
  // Show the new LED color:  
  for (int i=0; i<rgb.numPixels(); i++)
    rgb.setPixelColor(i, rgb.Color(map(blynkRed, 0, 255, 0, rgbMaxBrightness), 
                                   map(blynkGreen, 0, 255, 0, rgbMaxBrightness),
                                   map(blynkBlue, 0, 255, 0, rgbMaxBrightness)));
  rgb.show();
}
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

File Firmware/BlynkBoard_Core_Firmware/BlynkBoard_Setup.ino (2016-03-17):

/******************************************************************************
BlynkBoard_Setup.h
BlynkBoard Firmware: Board initialization functions
Jim Lindblom @ SparkFun Electronics
February 24, 2016
https://github.com/sparkfun/Blynk_Board_ESP8266/Firmware

This file, part of the BlynkBoard Firmware, defines the hardware setup and
initialization functions. That includes EEPROM and flash (SPIFFS) reading
and writing.

Resources:
ESP8266 File System (FS.h) - (included with ESP8266 Arduino board definitions)

License:
This is released under the MIT license (http://opensource.org/licenses/MIT).
Please see the included LICENSE.md for more information.

Development environment specifics:
Arduino IDE 1.6.7
SparkFun BlynkBoard - ESP8266
******************************************************************************/

bool initHardware(void)
{
  // Short delay at the start avoids intermittent Microsoft Serial 
  // Ballpoint driver from showing up.
  delay(1000); 
  Serial.begin(SERIAL_TERMINAL_BAUD);
  BB_PRINT("");
  BB_PRINT("SparkFun Blynk Board Hardware v" + String(BLYNKBOARD_HARDWARE_VERSION));
  BB_PRINT("SparkFun Blynk Board Firmware v" + String(BLYNKBOARD_FIRMWARE_VERSION));
  
  randomSeed(ESP.getChipId());
      
  // Initialize RGB LED and turn it off:
  rgb.begin();
  rgb.setPixelColor(0, rgb.Color(0, 0, 0));
  rgb.show();
  // Attach a timer to the RGB LED:
  blinker.attach_ms(RGB_PERIOD_AP, blinkRGBTimer);

  // Initialize the button, and setup a hardware interrupt
  // Look for CHANGE - when the button is pressed or released.
  pinMode(BUTTON_PIN, INPUT_PULLUP);
  attachInterrupt(BUTTON_PIN, buttonChange, CHANGE);

  // Initialize the LED pin:
  pinMode(BLUE_LED_PIN, OUTPUT);   // Set pin as an output
  digitalWrite(BLUE_LED_PIN, LOW); // Turn the LED off

  if (!SPIFFS.begin())
  {
    BB_DEBUG("Failed to initialize SPIFFS");
    return false;
  }
  
  EEPROM.begin(EEPROM_SIZE);
  return true;
}

bool checkConfigFlag(void)
{  
  byte configFlag = EEPROM.read(EEPROM_CONFIG_FLAG_ADDRESS);
  if (configFlag == 1)
    return true;
    
  return false;
}

bool checkFailAPSetupFlag(void)
{
  if (EEPROM.read(EEPROM_AP_SETUP_FAIL_FLAG) != AP_SETUP_FAIL_FLAG_VALUE)
    return false;
    
  return true;
}

void writeAPSetupFlag(bool pass)
{
  uint8_t apSetupFlag;
  if (pass) apSetupFlag = AP_SETUP_FAIL_FLAG_VALUE;
  else apSetupFlag = 0;
  EEPROM.write(EEPROM_AP_SETUP_FAIL_FLAG, apSetupFlag);
  EEPROM.commit();
}

bool writeBlynkConfig(String authToken, String host, uint16_t port)
{
  File authFile = SPIFFS.open(BLYNK_AUTH_SPIFF_FILE, "w");
  if (authFile)
  {
    BB_DEBUG("Opened " + String(BLYNK_AUTH_SPIFF_FILE));
    authFile.print(authToken);
    authFile.close();
    BB_DEBUG("Wrote file.");
  }
  else
  {
    BB_DEBUG("Failed to open file to write.");
    return false;
  }
  
  File hostFile = SPIFFS.open(BLYNK_HOST_SPIFF_FILE, "w");
  if (hostFile)
  {
    BB_DEBUG("Opened " + String(BLYNK_HOST_SPIFF_FILE));
    hostFile.print(host);
    hostFile.close();
    BB_DEBUG("Wrote " + String(BLYNK_HOST_SPIFF_FILE));
  }
  else
  {
    BB_DEBUG("Failed to open " + String(BLYNK_HOST_SPIFF_FILE));
    return false;
  }
  
  File portFile = SPIFFS.open(BLYNK_PORT_SPIFF_FILE, "w");
  if (portFile)
  {
    BB_DEBUG("Opened " + String(BLYNK_PORT_SPIFF_FILE));
    portFile.print(port);
    portFile.close();
    BB_DEBUG("Wrote " + String(BLYNK_PORT_SPIFF_FILE));
  }
  else
  {
    BB_DEBUG("Failed to open " + String(BLYNK_PORT_SPIFF_FILE));
    return false;
  }
  
  return true;
}

String getBlynkAuth(void)
{
  String retAuth;
  
  if (SPIFFS.exists(BLYNK_AUTH_SPIFF_FILE))
  {
    BB_DEBUG("Opening auth file.");
    File authFile = SPIFFS.open(BLYNK_AUTH_SPIFF_FILE, "r");
    if(authFile)
    {
      BB_DEBUG("File opened.");
      size_t authFileSize = authFile.size();
      // Only return auth token if it's the right size (32 bytes)
      if (authFileSize == BLYNK_AUTH_TOKEN_SIZE)
      {
        while (authFile.available())
        {
          retAuth += (char)authFile.read();
        }
      }
      authFile.close();
    }
    else
    {
      BB_DEBUG("Failed to open auth file.");
    }
  }
  else
  {
    BB_DEBUG("File does not exist.");
  }

  return retAuth;
}

String getBlynkHost(void)
{
  String retHost;
  
  if (SPIFFS.exists(BLYNK_HOST_SPIFF_FILE))
  {
    File hostFile = SPIFFS.open(BLYNK_HOST_SPIFF_FILE, "r");
    if(hostFile)
    {
      BB_DEBUG("Opened" + String(BLYNK_HOST_SPIFF_FILE));
      while (hostFile.available())
        retHost += (char)hostFile.read();
      hostFile.close();
    }
    else
    {
      BB_DEBUG("Failed to open " + String(BLYNK_HOST_SPIFF_FILE));
    }
  }
  else
  {
    BB_DEBUG(String(BLYNK_HOST_SPIFF_FILE) + " does not exist.");
  }

  return retHost;
}
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

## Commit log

2016-01-08 Initial commit of hardware.
    [SparkFun-Blynk-Thing.brd, SparkFun-Blynk-Thing.sch]
2016-01-11 Schematic cleanup
    [SparkFun-Blynk-Thing.brd, SparkFun-Blynk-Thing.sch]
2016-01-11 Board cleanup
    [SparkFun-Blynk-Thing.brd, SparkFun-Blynk-Thing.sch]
2016-01-11 Adding dimensions
    [SparkFun-Blynk-Thing.brd]
2016-01-11 Adjsting board dimension to 0.01in grid
    [SparkFun-Blynk-Thing.brd]
2016-01-11 Labeling battery connector.
    [SparkFun-Blynk-Thing.brd]
2016-01-11 Re-configuring the I2C connector.
    [SparkFun-Blynk-Thing.brd, SparkFun-Blynk-Thing.sch]
2016-01-11 Schematic cleanup, adding decoupling cap to batt charger
    [SparkFun-Blynk-Thing.brd, SparkFun-Blynk-Thing.sch]
2016-01-12 Schematic clean-up and some PROD_ID's
    [SparkFun-Blynk-Thing.brd, SparkFun-Blynk-Thing.sch]
2016-01-12 Adding PROD_ID's to U5 and JP14
    [SparkFun-Blynk-Thing.brd, SparkFun-Blynk-Thing.sch]
2016-02-04 Moving WS2812-VCC jumper.
    [SparkFun-Blynk-Thing.brd, SparkFun-Blynk-Thing.sch]
2016-02-04 Updating 32M Flash package.
    [SparkFun-Blynk-Thing.brd, SparkFun-Blynk-Thing.sch]
2016-02-04 Fixing Op amp power supply.
    [SparkFun-Blynk-Thing.brd, SparkFun-Blynk-Thing.sch]
2016-02-04 Fixing Si7021 tCream and tStop.
    [SparkFun-Blynk-Thing.brd, SparkFun-Blynk-Thing.sch]
2016-02-05 Moving headers in to fit in breadboard.
    [SparkFun-Blynk-Thing.brd]
2016-02-05 Upping version to v02
    [SparkFun-Blynk-Thing.brd, SparkFun-Blynk-Thing.sch]
2016-02-05 Fixing board name silk
    [SparkFun-Blynk-Thing.brd]
2016-02-05 Swapping JST connectors on I2C footprint.
    [SparkFun-Blynk-Thing.brd, SparkFun-Blynk-Thing.sch]
2016-02-05 Silkscreen fixes
    [SparkFun-Blynk-Thing.brd]
2016-02-05 Updating 4-pin JST PROD_ID
    [SparkFun-Blynk-Thing.brd, SparkFun-Blynk-Thing.sch]
2016-02-05 created proto panel v02
    [SparkFun-Blynk-Thing-ProtoPanel_v02.brd]
2016-02-08 Updating board name on silkscreen.
    [SparkFun-Blynk-Thing.brd, SparkFun-Blynk-Thing.sch]
2016-02-15 Changing file names to match product name.
    [SparkFun-Blynk-Board-ESP8266.brd, SparkFun-Blynk-Board-ESP8266.sch]
2016-02-15 Moving some silk. Updating version number to v10.
    [SparkFun-Blynk-Board-ESP8266.brd, SparkFun-Blynk-Board-ESP8266.sch]
2016-02-15 Fixing default layers.
    [SparkFun-Blynk-Board-ESP8266.brd]
2016-02-15 Moving PWR led a bit away from screwhead.
    [SparkFun-Blynk-Board-ESP8266.brd]
2016-02-15 Updating PROD_ID on JP29.
    [SparkFun-Blynk-Board-ESP8266.brd, SparkFun-Blynk-Board-ESP8266.sch]
2016-02-15 created panel v10
    [SparkFun-Blynk-Board-ESP8266_Panel_v10.brd]
2016-02-24 Initial commit of Blynk Board core firmware
2016-02-29 Adding board-selection info to readme.
2016-03-01 Squash random exception(0) crashses
    - Changing Blynk.virtualWrite's of Strings to floats.
    - Fixing battery virtual variable names
    [BlynkBoard_BlynkMode.ino, BlynkBoard_settings.h]
2016-03-01 Cleaning up config mode process
    - Going comment-crazy on Core firmware
    - Adding MODE_WAIT_CONFIG - if WiFi or Blynk fail to connect on startup,
    press the GP0 button to re-enter config mode.
    - Adding support to break out of WiFi or Blynk connect using GP0 button
    - Merging WiFi and Blynk connect functionality into singular functions in
    BlynkBoard_Setup.ino
    [BlynkBoard_ConfigMode.ino, BlynkBoard_Core_Firmware.ino, BlynkBoard_Setup.ino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]
2016-03-02 Fixing startup bug - EEPROM defaults to 255.
    [BlynkBoard_Setup.ino, BlynkBoard_settings.h]
2016-03-03 Fixing IP address print
    [BlynkBoard_ConfigMode.ino]
2016-03-03 Cleaning up BlynkBoard Blynk Mode
    - Moving as many functions out of loop as possible
    - Updating virtual pin numbers to match experiment order
    - Adding Blynk demo functionality
2016-03-03 Cleaning up BlynkMode, fixing button-press bug
    [BlynkBoard_BlynkMode.ino, BlynkBoard_settings.h]
2016-03-04 recreated panel v10 for better routing
    [SparkFun-Blynk-Board-ESP8266_Panel_v10a.brd]
2016-03-04 Flushing after terminal prints.
2016-03-04 Fixing W25Q32FVSS footprint.
2016-03-07 Reverting button-checks back to polling. Running into debounce errors.
    [BlynkBoard_BlynkMode.ino, BlynkBoard_settings.h]
2016-03-08 Added code for two devices.
2016-03-09 Fixing open network connect in serial config & error connect at startup.
    [BlynkBoard_ConfigMode.ino, BlynkBoard_Setup.ino, BlynkBoard_settings.h]
2016-03-09 Switching light updates to polling.
2016-03-10 Persistent SSID color codes through reset. Default to color code mode.
    [BlynkBoard_ConfigMode.ino, BlynkBoard_Core_Firmware.ino, BlynkBoard_settings.h]
2016-03-10 Adding host/port input framework.
2016-03-10 Fixing Blynk re-connect errors.
    [BlynkBoard_Core_Firmware.ino, BlynkBoard_settings.h]
2016-03-11 Add board_info.json WebPage styling Sorting of webpage SSIDs
2016-03-11 Adding button hold timer. Hold GP0 down for 3 seconds to re-enter config mode.
2016-03-11 Fixed up description in header
    [Bridge_Example_1.ino, Bridge_Example_2.ino]
2016-03-11 Making root page more responsive to low-res devices.
2016-03-14 Validate html and fix some labels
    [BlynkBoard_ConfigMode.ino]
2016-03-14 Adding check to RGB. If invalid number of params, ESP8266 was crashing.
    [BlynkBoard_BlynkMode.ino]
2016-03-14 Fixing reconnect errors, and 0.0.0.0 access point bug
    [BlynkBoard_ConfigMode.ino, BlynkBoard_Core_Firmware.ino, BlynkBoard_Setup.ino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]
2016-03-14 Allow resetting EEPROM using button in DEBUG mode
    [BlynkBoard_Core_Firmware.ino]
2016-03-14 Fix mobile webpage rendering
    [BlynkBoard_ConfigMode.ino]
2016-03-15 Adding framework for self-test, comment cleanup.
2016-03-15 Fixing Blynk connect timeout - was wayyy to long.
    [BlynkBoard_Setup.ino]
2016-03-15 Re-thinking Blynk connect timeout. Checking against millis.
2016-03-16 Oops, fixing Blynk timeout logic.
    [BlynkBoard_Setup.ino, BlynkBoard_settings.h]
2016-03-16 Adding adustable brightness to RGB LED.
2016-03-16 Adding periodic splashscreen updates, in case they're not caught in blynk connect
2016-03-17 Adding check if came out of AP-setup-fail reset.
    [BlynkBoard_ConfigMode.ino, BlynkBoard_Core_Firmware.ino, BlynkBoard_Setup.ino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]
2016-03-17 Re-working push project. Fixing default hostname in serial print.
    [BlynkBoard_BlynkMode.ino, BlynkBoard_settings.h]
2016-03-17 Slight fix to self-test mode.
    [BlynkBoard_Core_Firmware.ino, BlynkBoard_Setup.ino, BlynkBoard_settings.h]
2016-03-17 Adding delay at start - else board's intermittently pop up as serial ballpoint mice :S
2016-03-25 Fixing Blynk Board in Arduino IDE readme text
2016-03-25 Adding values to all parts
    [SparkFun-Blynk-Board-ESP8266.brd, SparkFun-Blynk-Board-ESP8266.sch]
2016-03-29 Adding value to 2-pin JST
    [SparkFun-Blynk-Board-ESP8266.brd, SparkFun-Blynk-Board-ESP8266.sch]
2016-03-31 Fixing timer display on LCD
    [Laundry_Monitor.ino]
2018-04-10 Comment experiment 9 servo wrong
    It is mentioned to use split mode V14,V15, but it should be merge mode V14
    [BlynkBoard_BlynkMode.ino]
2019-01-23 Fixed SELF_TEST_ENABLED being defined
    By having SELF_TEST_ENABLED on line 29, the code enters the conditional statement on line 107, which will have it run a modified self-test function. According to line 112, and confirmed by multiple tests, the performSelfTest() function will end in an infinite loop on both success or fail, which binds the code and does not let it continue to the MODE_WAIT_CONFIG runMode.
    [BlynkBoard_Core_Firmware.ino]
2020-04-13 Adding a Requirement for ISR when using the ESP8266 Community Board Add-On
    The SparkFun Blynk board add-on is now supported by
    the ESP8266 Community! If you are installing the ESP8266
    board add-on v2.6.0+ and using an interrupt service routine,
    you must include `ICACHE_RAM_ATTR` before the function
    definition. This was a requirement after v2.5.1+. If users do not add this before the ISR, the examples will not run even though it can compile/upload via the Arduino IDE.
2020-04-13 Add Comment and "Update Firmware Number"
    - add comment about SELF_TEST_ENABLED
    - update firmware version number to distinguish the ones used with production and the ESP8266 Community's board file (v2.6.0 and above) which requires a `ICACHE_RAM_ATTR` to be placed before ISR defi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
    - overall, this should not affect the board's functionality when using it with the Blynk App
2020-04-13 Update README.md
    The SparkFun Blynk Board add is now supported by the [ESP8266 Community](https://github.com/esp8266/Arduino) as of v2.6.0! Updating to point to their board url.

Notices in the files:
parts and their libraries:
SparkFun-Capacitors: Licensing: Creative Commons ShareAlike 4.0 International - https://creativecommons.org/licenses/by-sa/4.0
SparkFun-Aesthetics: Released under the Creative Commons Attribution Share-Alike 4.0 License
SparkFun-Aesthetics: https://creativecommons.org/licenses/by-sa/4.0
